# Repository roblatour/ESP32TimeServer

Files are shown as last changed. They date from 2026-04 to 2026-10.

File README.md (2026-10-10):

# ESP32 NTP Stratum 1 Time Server (version 3.0.4)

An ESP32 NTP Stratum 1 Time Server for your home network



---

## Overview

This project was born with a simple goal: create a low-budget, **Stratum 1 NTP
time server** solution with no need for periodic Linux OS updates. Rather just
set it up and let it do its job.

ESP32 Time Server

It uses a **GNSS (North America & Europe) receiver** as its time source, making
it a true Stratum 1 server — meaning it gets its time directly from satellites
rather than from another NTP server. Every device on your home network can then
synchronize to it for highly accurate local time.

---

## What's New

**Current Version (3.0+)**
- **NTPv4 Symmetric-key authentication** added for Windows 
  clients using Meinberg and Linux clients using chrony.  For more 
  information, please see [this document](misc/symmetric_key_authentication_setup.md).
- **WS2182** RGB LED support added (KY-016 support continues).

**Version 2** was a ground-up rewrite which came with a faster, more capable board 
support and a long list of accuracy, reliability, and convenience improvements over
version 1, including:

- **Higher accuracy, lower jitter** — full use of the GPS module's PPS
  (Pulse Per Second) pin disciplines the clock for sub-millisecond accuracy,
  with hardware time stamping and RFC 9769-compatible interleaved responses
  further reducing jitter for both NTPv3 and NTPv4 requests.
- **Faster, more modern hardware** — built around the WaveShare ESP32-P4-ETH
  (or the newer ESP32-P4-WIFI6-ETH), a significant step up from the
  ESP32-WROOM-32/32E used in v1.
- **Broader GNSS module support** — still works great with the recommended
  SparkFun MAX-M10S, but also supports lower-cost generic GNSS modules and now
  has experimental support for the GT-U16, which offers better reception than
  some competing receivers at the same or higher price points.
- **Wireless firmware updates** — Over-the-Ethernet OTA updates let you push
  new firmware directly from VS Code, with on-screen progress shown on the
  LCD, so you rarely need to plug in a cable after the first flash.
- **Handles more traffic** — greatly increased throughput and concurrent
  request handling, so the server keeps up even on busy networks.
- **IPv6 support** — the server now responds to NTP requests over IPv6 as
  well as IPv4.
- **Flexible networking** — set a custom MAC address or a static IP, instead
  of always relying on the device's default address and DHCP.
- **Optional LCD support** — a 4x20 LCD screen was required in v1; 
  in v2 it's entirely optional, along with an optional up time / reset button.
- **Optional RGB LED support added** — [here](misc/status_indicators.md)
  is how that is used.
- **Smart GNSS lock tracking** — improved satellite lock and PPS discipline
  tracking, with results correctly reported as Stratum 16 (undefined) if lock
  or discipline is temporarily lost, and automatic recovery once it's
  restored.
- **Quick restarts** — GPS module identity and baud rate are saved to
  non-volatile storage, so the server starts up quickly after the initial
  setup.
- **MQTT publishing** — optionally publish time server stats to an MQTT
  broker, with TF card support for queueing far more messages if the broker
  connection drops.
- **Home Assistant integration** — ready-made entity and dashboard setup
  instructions for pulling time server stats into Home Assistant.
- **Built-in self-test** — an optional startup health check lets the server
  verify its own core functionality every time it boots.
- **Testing tools and guidance** — instructions, tools, and links for
  measuring jitter, drift, RFC 9769 compliance, memory usage, and server
  performance under stress.
- **Updated 3D printed case** — enclosure files refreshed for the new
  WaveShare ESP32-P4-ETH board.

 **Version 1** described in detail [here](https://hackaday.io/project/189309-esp32-ntp-time-server-stratum-1) was built for Arduino / PlatformIO and remains available
 [here](https://github.com/roblatour/ESP32TimeServer/releases/tag/v1.0.0.0).
>
([Detailed release history](https://github.com/roblatour/ESP32TimeServer/releases))

---

## Hardware

| Qty | Item |
| --- | --- |
| 1 | WaveShare [ESP32-P4-ETH](https://www.waveshare.com/esp32-p4-eth.htm?sku=32086) or [ESP32-P4-WIFI6-ETH](https://www.waveshare.com/esp32-p4-wifi6-poe-eth.htm?sku=32832) development board (with or without optional PoE) <sup>1 2</sup> |
| 1 | GPS/GNSS module [Recommended: SparkFun GNSS Receiver Breakout - MAX-M10S (Qwiic)](https://www.sparkfun.com/sparkfun-gnss-receiver-breakout-max-m10s-qwiic.html) <sup>2</sup>. Additionally, experimental support for the [GT U16](https://www.aliexpress.com/item/1005008288311771.html) has been added in version 2.9 - this receiver offers superior reception when coupled with the right antenna (see notes below).  Additionally, while some lower-cost generic modules UBlox compliant receivers are supported, those without a PPS pin are no longer supported. |
| 1 | GPS/GNSS antenna with SMA connector ([SparkFun GPS/GNSS Magnetic Mount Antenna - 3m (SMA)](https://www.sparkfun.com/products/14986)) <sup>2</sup>. Alternatively the GT U16 with an L1/L5 antenna offers superior reception.  However, in my testing I used the [3M SMA W70C](https://www.aliexpress.com/item/1005008421771962.html?spm=a2g0o.order_list.order_list_main.11.7a7f1802GCXbvZ) L1/L2/L5 antenna an [IPEX to SMA adapter](https://www.aliexpress.com/item/1005009047225776.html) and got very good results (I have the antenna bundled with the GT U16 (link above) on order and when I get it and test it I will update this page). |
| 1 | _(Optional)_ TF Card, formatted as FAT32, if you're using MQTT and want more than four messages queued should broker communications be down) <sup>2</sup> |
| 1 | _(Optional)_ RGB LED: KY-016 ([AliExpress](https://www.aliexpress.com/item/32763280158.html)) or WS2812 ([AliExpress](https://www.aliexpress.com/item/1005009109749689.html)) with a 470&Omega; resistor and optional lens cap ([AliExpress](https://www.aliexpress.com/store/625859)) |
| 1 | _(Optional)_ 4×20 I²C LCD display with HD44780 controller with PCF8574 I²C backpack ([AliExpress](https://www.aliexpress.com/item/1005006829045609.html)) <sup>2</sup> |
| 1 | _(Optional)_ Momentary push button for displaying up time and triggering a reset ([AliExpress](https://www.aliexpress.com/item/1005004066257419.html)) <sup>2</sup> |
| 1 | _(Optional)_ USB C extension cable (with right angle end) ([AliExpress](https://www.aliexpress.com/item/1005006584965187.html)) <sup>2</sup> + two M3*8 |
| — | Miscellaneous: Ethernet cable, female dupont connection wires, small 4" .1" zip ties, solder <sup>2</sup> |
| — | A PoE-capable switch, PoE injector, **or** USB-C power supply and USB-C cable |

> ⚠️ **WARNING — Do NOT power the ESP32-P4-POE-ETH or the ESP32-P4-WIFI6-POE-ETH
> via both its USB-C connector and a PoE powered Ethernet cable at the same time.**
> Powering from both simultaneously may damage the ESP32-P4-ETH board, POE switch,
> or device providing USB power. Either power source alone is sufficient to
> power the board, GPS module, and LCD screen.

<sup>1</sup> See notes in the 'What's New in Version 2' section above.

<sup>2</sup> _(Optional)_ there are 3D Printable Case designed for use
with ESP32-P4_ETH and these specific components (for more information see below).

_(Also Optional)_ To cut down on wiring a PCB can be used. One designed
to work within this project's 3D printed enclosure is available in the
[`PCB`](./PCB) folder. If your interested, please review the `Readme.md` file in
that folder for more information.

### Wiring

#### GPS module → ESP32-P4-ETH _(mandatory)_

| GPS pin | ESP32-P4-ETH pin |
| --- | --- |
| GND | GND |
| VCC | 3V3 |
| PPS | GPIO 20 |
| TXD | GPIO 21 (RX) |
| RXD | GPIO 22 (TX) |

**Pro Tip:** (Optionally) Adding a capacitor between the GNSS module's Vcc and GND power pins,
placed as close as possible to those pins, can improve GNSS power supply stability. Use a
100nf (aka 0.1μf, aka 104) ceramic capacitor, rated at least 50v, 
such as [this one](https://www.aliexpress.com/item/1005004469852680.html).

**Important:**
 
Some GNSS receivers and breakout boards provide a 3.3v PPS (Pulse-Per-Second) output pin
while others provide a 5v PPS output pin.

1. Only connect a 3.3v PPS pin to an ESP32 GPIO pin, never connect a 5v PPS pin to an ESP32 GPIO pin

2. For the wire between the ESP32-P4's GPIO pin and the GNSS Receiver's PPS pin
use as short and as well connect wire as possible; a standard copper Dupont wire
will be fine assuming its gauge is between 24 AWG and 28 AWG

3. The GNSS GND must be connected to the ESP32 GND

Also of note, the above PPS, TX, and RX pin selections were changed in version 2.4 for better
forward and backward compatibility between revisions of the ESP32-P4 chip.
However, if an earlier version of the software has been working fine for you
then you may be able to use the old pin specifications if you want to avoid
rewiring your project. Please see the ESP32TimeServerSettings.h file for more
information.

#### Up time / Reset button → ESP32-P4-ETH _(optional)_

| Button | ESP32-P4-ETH pin |
| --- | --- |
| One terminal | GND |
| The other terminal | GPIO 3 |

#### WS2812 RGB LED _(optional)_

| LCD pin | | ESP32-P4-ETH pin |
| --- | --- | --- |
| GND | | GND |
| DI | 470&Omega; resistor | GPIO 4 |
| 5v | | V5 / VBUS |
> **Important** with the WS2812 a 470&Omega; resistor is require between the DI and GPIO 4 pin

#### KY-016 RGB LED _(optional)_

| LCD pin | ESP32-P4-ETH pin |
| --- | --- |
| GND | GND |
| BLUE | GPIO 4 |
| GREEN | GPIO 5 |
| RED | GPIO 6 |

#### LCD 2004 (HD44780 + PCF8574 I²C backpack) → ESP32-P4-ETH _(optional)_

| LCD pin | ESP32-P4-ETH pin |
| --- | --- |
| GND | GND |
| VCC | 3V3 |
| SLC/SCL | GPIO 7 |
| SDA | GPIO 8 |

Refer to the pin definitions in
[`main/ESP32TimeServerSettings.h`](./main/ESP32TimeServerSettings.h).

---

## 3D Printed Case

A downloadable 3D printable enclosure designed for use the WaveShare
ESP32-P4-ETH (with or without the POE hat) + Sparkfun GPS boards is included in
the [`3D printable case/`](./3D%20printable%20case/) folder. Both `.stl`
(print-ready) and `.f3z` (Fusion 360 editable source) files are provided so you
can tweak the design to suit your needs.

> **Note:** the 3D printable enclosure files also includes the needed models for
> version 1 (used an Olimex ESP32-PoE-ISO Rev. B dev board).

---

## Software

### Build and development environment

**To build and flash ESP32TimeServer** you will need **Espressif's ESP-IDF v6.1** or above. 
If you don't already have this software installed, just follow the install instructions
directly below:

https://docs.espressif.com/projects/esp-idf/en/stable/esp32/get-started/index.html

which include these links to get it:

[Installation of ESP-IDF and Tools on Windows](https://docs.espressif.com/projects/esp-idf/en/stable/esp32/get-started/windows-setup.html)

[Installation of ESP-IDF and Tools on Linux](https://docs.espressif.com/projects/esp-idf/en/stable/esp32/get-started/linux-setup.html)

[Installation of ESP-IDF and Tools on macOS](https://docs.espressif.com/projects/esp-idf/en/stable/esp32/get-started/macos-setup.html)

If you want to further develop the project, Visual Studio Code with the ESP-IDF extension is recommended.
However, they are not needed to build and flash the project - the instructions for that are below.

Both Visual Studio Code (Community Edition) and the ESP-IDF extension are free to download and use.
Here is where you can find more information about them and get your copies:

- **[Visual Studio Code](https://code.visualstudio.com/)**
- **[Espressif ESP-IDF Extension for VS Code](https://marketplace.visualstudio.com/items?itemName=espressif.esp-idf-extension)**

#### **For Linux users:**
A kind user of this project has shared more detailed environment setup, build and flash instructions specific to Linux (Debian 13) - these can be found [here](misc/Linux_specific_setup_instructions.md)

### Dependencies

The
[`SparkFun u-blox GNSS Arduino Library v3`](https://github.com/sparkfun/SparkFun_u-blox_GNSS_v3)
(v3.1.14) is included as a **git submodule** in
[`3rdparty/SparkFun_u-blox_GNSS_v3`](./3rdparty/SparkFun_u-blox_GNSS_v3). The
local component wrapper in `components/SparkFun_u-blox_GNSS_v3` builds it from
that checked-out submodule.

The remaining dependencies are managed automatically via the ESP-IDF Component
Manager (declared in [`main/idf_component.yml`](./main/idf_component.yml)):

- `esp-idf-lib/hd44780` — LCD driver
- `esp-idf-lib/pcf8574` — I²C LCD backpack driver
- `espressif/arduino-esp32` — Arduino compatibility layer for OTA and serial
- `espressif/mqtt` — MQTT client used for optional reporting

> **Note:** The ESP-IDF Component Manager resolves these dependencies
> dynamically at build time. A `dependencies.lock` file is generated locally on
> first build but is intentionally not committed because it is git-ignored.

## Setup

### Setup Step 1 - Download

Create a folder for this project, clone this repository into it, and update the
SparkFun library within it. For example:

```cmd
c:
```

```cmd
mkdir c:\temp\ESP32TimeServerProject
```

```cmd
cd \temp\ESP32TimeserverProject
```

```cmd
git clone --recursive https://github.com/roblatour/ESP32TimeServer
```

```cmd
cd ESP32TimeServer
```

```cmd
git submodule update --init --recursive
```

### Setup Step 2 - Configuration

All user-configurable settings — GPIO pins, GPS options, LCD options, button
support, time zone, etc. — are centralized in:

```plaintext
main/ESP32TimeServerSettings.h
```

Edit this file to match your desired hardware setup before building.

> **Note:** The settings file indicates whether certain features are enabled.
> These include support for an Uptime/Restart Button, a Liquid Crystal Display,
> MQTT reporting, and Over the Ethernet Updates. Please also note, that if a
> Liquid Crystal Display is **not** connected, `LIQUID_CRYSTAL_DISPLAY_ENABLED`
> **must** be `0` (disabled) or a critical runtime error will occur.

### Setup Step 3 - Build

Open a Command Prompt, load the ESP-IDF 6.1 environment, and remove any
existing generated configuration before building. The first build downloads the
Component Manager dependencies into `managed_components`; this generated folder
is not part of the repository. 

Enter the commands below to setup the build environment and build the project:

```cmd
call C:\esp\v6.1\esp-idf\export.bat
```
```cmd
if exist sdkconfig del sdkconfig
```

You will need to know your ESP32-P4 chip's revision number to build the program. To determine it connect your ESP32-P4 development board to your computer via a USB cable and enter the following command:

```cmd
esptool.py -p COMx flash-id
```

> Note: Replace `COMx` with your actual serial port. For example: COM6

The output of the above includes chip type and revision number.

Next, use the command below matching your ESP32-P4's chip revision number to build the project:

- For ESP32-P4 chips at revision 3.1 and above (including the 
  **WaveShare ESP32-P4-WIFI6-POE-ETH and newer WaveShare 
  ESP32-P4-ETH** development boards):

  ```cmd
  idf.py -D SDKCONFIG_DEFAULTS="sdkconfig.defaults;config/esp32p4_rev_v3_1.defaults" set-target esp32p4 build
  ```
- For ESP32-P4 chips at revision 3.0:

  ```cmd
  idf.py -D SDKCONFIG_DEFAULTS="sdkconfig.defaults;config/esp32p4_rev_v3_0.defaults" set-target esp32p4 build
  ```
- For older ESP32-P4 chips with revisions prior to version 3.0 (including older 
  **Waveshare ESP32-P4-ETH** development boards):

  ```cmd
  idf.py -D SDKCONFIG_DEFAULTS="sdkconfig.defaults;config/esp32p4_rev_pre_v3.defaults" set-target esp32p4 build
  ```

### Setup Step 4 - Flash

In the same Command Prompt where ESP-IDF 6.1 was loaded:

```cmd
idf.py -p COMx flash monitor
```

> Note: Replace `COMx` with your actual serial port. For example: COM6
>
> **Important:** Do not use `--force` to flash an image to an earlier revision
> ESP32-P4.

### Over The Ethernet (OTE) Updates

Following the initial flash, OTE updates can be performed if
`OTE_UPDATES_ENABLED` was set to `1` (Enabled) for the initial build and flash.

A VS Code task **"ESP-IDF: OTE Upload over Ethernet"** is included in
`.vscode/tasks.json`. It builds the firmware and deploys it to the device over
Ethernet using `espota.py`, so no USB cable is needed after the first flash.
Alternatively, use the terminal command in
[`UsefulPowerShellCommands.md`](./misc/UsefullPowerShellCommands.md) in the
`misc` folder.

---

## Setting up your Network / Systems to make use of the ESP32 Time Server

Please see [`Setup.md`](misc/Setup.md)

---

## Validating Your Time Server

Once running, and with your Network and System changes setup, you can validate
accuracy at [https://time.is](https://time.is).

You're also welcome to use this open source software (also developed by me) to
stress test your time server:

<https://github.com/roblatour/TimeServerStressTest>

---

## License

This project is released under the **MIT License** — see the [LICENSE](LICENSE)
file for details.

---

## Supporting This Project

To help support this project, or to just say thanks, you're welcome to 'buy me a
coffee'.

[buy me a coffee](https://www.buymeacoffee.com/roblatour)

---

Copyright © 2026 Rob Latour

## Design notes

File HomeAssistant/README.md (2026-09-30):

# ESP32 Time Server — Home Assistant Dashboard Card Setup

This guide covers how to integrate the ESP32 Time Server with Home Assistant and
display a status dashboard card. It is **not** an exhaustive write-up; it is
intended to get things up and running within an already existing Home Assistant
implementation.

The steps covered are:

1. Install and configure the Mosquitto MQTT broker add-on
2. Configure `mqtt.yaml` with the ESP32 Time Server sensors
3. Update `configuration.yaml` with an MQTT reference and template sensors
4. Reload the Home Assistant YAML configuration
5. Add a dashboard entity card

When complete, your dashboard will include a card like this:

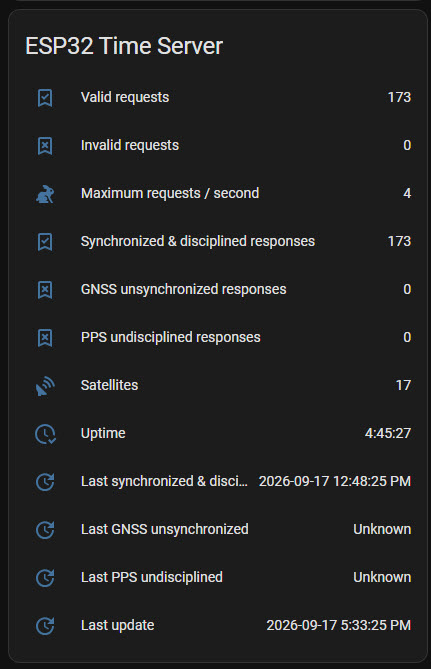
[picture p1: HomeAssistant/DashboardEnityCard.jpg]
ESP32 Time Server Dashboard Card


---

## Step 1: Install the Mosquitto MQTT Broker

The ESP32 Time Server publishes its status data over MQTT. Home Assistant needs
a running MQTT broker to receive those messages.

The recommended broker for Home Assistant is the Mosquitto broker add-on. Follow
the official Home Assistant documentation to install and configure it before
continuing:

- **MQTT integration overview:**
  <https://www.home-assistant.io/integrations/mqtt/>
- **Mosquitto broker add-on:**
  <https://github.com/home-assistant/addons/blob/master/mosquitto/DOCS.md>

Once the Mosquitto broker is running and the MQTT integration is connected to
it, proceed to Step 2.

---

## Step 2: Configure mqtt.yaml

The MQTT sensors tell Home Assistant how to extract individual values from the
JSON payload that the ESP32 Time Server publishes to the
`ESP32TimeServer/report` topic.

Choose **one** of the three options below based on your current setup. After
completing this step, proceed to the matching option in Step 3.

### A — Create a new mqtt.yaml file

Use this option if you do **not** already have an `mqtt.yaml` file.

1. Create a new file called `mqtt.yaml` in your Home Assistant configuration
   directory (the same folder that contains `configuration.yaml`).
2. Add the following content:

```yaml

  sensor:
    # ============================
    # CURRENT
    # ============================
    - name: "NTP Time"
      state_topic: "ESP32TimeServer/report"
      value_template: "{{ value_json.current.time }}"

    - name: "NTP Uptime"
      state_topic: "ESP32TimeServer/report"
      value_template: "{{ value_json.current.uptime }}"
      unit_of_measurement: "s"

    - name: "Ethernet Up"
      state_topic: "ESP32TimeServer/report"
      value_template: "{{ value_json.current.ethernet_up }}"

    - name: "GNSS Synchronized"
      state_topic: "ESP32TimeServer/report"
      value_template: "{{ value_json.current.gnss_synchronized }}"

    - name: "GNSS Locked"
      state_topic: "ESP32TimeServer/report"
      value_template: "{{ value_json.current.gnss_synchronized_indicators.locked }}"

    - name: "GNSS Timing Valid"
      state_topic: "ESP32TimeServer/report"
      value_template: "{{ value_json.current.gnss_synchronized_indicators.timing }}"

    - name: "GNSS GPS Valid"
      state_topic: "ESP32TimeServer/report"
      value_template: "{{ value_json.current.gnss_synchronized_indicators.gps_valid }}"

    - name: "GNSS Sync Fresh"
      state_topic: "ESP32TimeServer/report"
      value_template: "{{ value_json.current.gnss_synchronized_indicators.sync_fresh }}"

    - name: "GNSS Sanity Check Passed"
      state_topic: "ESP32TimeServer/report"
      value_template: "{{ value_json.current.gnss_synchronized_indicators.sanity_check_passed }}"

    - name: "PPS Disciplined"
      state_topic: "ESP32TimeServer/report"
      value_template: "{{ value_json.current.pps_disciplined }}"

    - name: "PPS Signals Present"
      state_topic: "ESP32TimeServer/report"
      value_template: "{{ value_json.current.pps_disciplined_indicators.pps_signals_present }}"

    - name: "PPS Discipline Active"
      state_topic: "ESP32TimeServer/report"
      value_template: "{{ value_json.current.pps_disciplined_indicators.discipline_active }}"

    - name: "PPS Synchronized"
      state_topic: "ESP32TimeServer/report"
      value_template: "{{ value_json.current.pps_disciplined_indicators.pps_synchronized }}"

    - name: "Satellites Current"
      state_topic: "ESP32TimeServer/report"
      value_template: "{{ value_json.current.satellites }}"

    # ============================
    # MEMORY
    # ============================
    - name: "Malloc DMA"
      state_topic: "ESP32TimeServer/report"
      value_template: "{{ value_json.current.memory.malloc_cap_dma }}"

    - name: "Free Heap"
      state_topic: "ESP32TimeServer/report"
      value_template: "{{ value_json.current.memory.free_heap }}"

    - name: "Minimum Free Heap"
      state_topic: "ESP32TimeServer/report"
      value_template: "{{ value_json.current.memory.minimum_free_heap }}"

    - name: "Largest Free 8-bit Block"
      state_topic: "ESP32TimeServer/report"
      value_template: "{{ value_json.current.memory.largest_free_8bit_block }}"

    # ============================
    # QUEUED MESSAGES
    # ============================
    - name: "Queued Held"
      state_topic: "ESP32TimeServer/report"
      value_template: "{{ value_json.queued_messages.held }}"

    - name: "Queued Discarded"
      state_topic: "ESP32TimeServer/report"
      value_template: "{{ value_json.queued_messages.discarded }}"

    # ============================
    # THIS PERIOD
    # ============================
    - name: "Ethernet Up Seconds"
      state_topic: "ESP32TimeServer/report"
      value_template: "{{ value_json.this_period.ethernet_up_secs }}"
      unit_of_measurement: "s"

    - name: "PPS Pulses"
      state_topic: "ESP32TimeServer/report"
      value_template: "{{ value_json.this_period.pps_pulses }}"

    - name: "GNSS Locked Seconds"
      state_topic: "ESP32TimeServer/report"
      value_template: "{{ value_json.this_period.gnss_locked_secs }}"
      unit_of_measurement: "s"

    - name: "Satellites Min"
      state_topic: "ESP32TimeServer/report"
      value_template: "{{ value_json.this_period.satellites.min }}"

    - name: "Satellites Max"
      state_topic: "ESP32TimeServer/report"
      value_template: "{{ value_json.this_period.satellites.max }}"

    - name: "NTP Requests Valid"
      state_topic: "ESP32TimeServer/report"
      value_template: "{{ value_json.this_period.ntp.requests.valid }}"

    - name: "NTP Requests Invalid"
      state_topic: "ESP32TimeServer/report"
      value_template: "{{ value_json.this_period.ntp.requests.invalid }}"
      
    - name: "NTP Requests Authenticated Valid"
      state_topic: "ESP32TimeServer/report"
      value_template: "{{ value_json.this_period.ntp.requests.authenticated.valid }}"

    - name: "NTP Requests Authenticated Invalid"
      state_topic: "ESP32TimeServer/report"
      value_template: "{{ value_json.this_period.ntp.requests.authenticated.invalid }}"

    - name: "NTP Requests Unauthenticated Valid"
      state_topic: "ESP32TimeServer/report"
      value_template: "{{ value_json.this_period.ntp.requests.unauthenticated.valid }}"

    - name: "NTP Requests Unauthenticated Invalid"
      state_topic: "ESP32TimeServer/report"
      value_template: "{{ value_json.this_period.ntp.requests.unauthenticated.invalid }}"

    - name: "Load Shedding"
      state_topic: "ESP32TimeServer/report"
      value_template: "{{ value_json.this_period.ntp.requests.load_shedding }}"

    - name: "NTP Telemetry Dropped"
      state_topic: "ESP32TimeServer/report"
      value_template: "{{ value_json.this_period.ntp.requests.telemetry_dropped }}"

    - name: "NTP Max Requests Per Second"
      state_topic: "ESP32TimeServer/report"
      value_template: "{{ value_json.this_period.ntp.requests.max_per_second }}"

    - name: "NTP Responses Synchronized & Disciplined"
      state_topic: "ESP32TimeServer/report"
      value_template: "{{ value_json.this_period.ntp.responses.synchronized_and_disciplined }}"

    - name: "NTP Responses GNSS Unsynchronized"
      state_topic: "ESP32TimeServer/report"
      value_template: "{{ value_json.this_period.ntp.responses.gnss_unsynchronized }}"

    - name: "NTP Responses PPS Undisciplined"
      state_topic: "ESP32TimeServer/report"
      value_template: "{{ value_json.this_period.ntp.responses.pps_undisciplined }}"

    # ============================
    # CLIENTS
    # ============================
    - name: "Clients Overflown"
      state_topic: "ESP32TimeServer/report"
      value_template: "{{ value_json.this_period.clients_overflown }}"

    # Example for client 0 (you can add more if desired)
    - name: "Client 0 Address"
      state_topic: "ESP32TimeServer/report"
      value_template: "{{ value_json.this_period.clients[0].address }}"

    - name: "Client 0 Requests"
      state_topic: "ESP32TimeServer/report"
      value_template: "{{ value_json.this_period.clients[0].requests }}"

    # ============================
    # HISTORICAL
    # ============================
    - name: "Last Synchronized & Disciplined"
      state_topic: "ESP32TimeServer/report"
      value_template: "{{ value_json.historical.gnss_receiver_last.synchronized_and_disciplined }}"

    - name: "Last GNSS Unsynchronized"
      state_topic: "ESP32TimeServer/report"
      value_template: "{{ value_json.historical.gnss_receiver_last.gnss_unsynchronized }}"

    - name: "Last PPS Undisciplined"
      state_topic: "ESP32TimeServer/report"
      value_template: "{{ value_json.historical.gnss_receiver_last.pps_undisciplined }}"

```

### B — Append to an existing mqtt.yaml

Use this option if you already have an `mqtt.yaml` file that contains a
`sensor:` list.

1. Open your existing `mqtt.yaml`.
2. Scroll to the end of the `sensor:` list and append the entries below. Each
   entry is indented two spaces (to sit under the existing `sensor:` key). If
   your file does not yet have a `sensor:` key, add `sensor:` on its own line
   first, then paste the entries beneath it.

```yaml
  
  # only add the sensor key line below if your existing file currently doesn't already have a sensor key line
  sensor:

    # ============================
    # CURRENT
    # ============================
    - name: "NTP Time"
      state_topic: "ESP32TimeServer/report"
      value_template: "{{ value_json.current.time }}"

    - name: "NTP Uptime"
      state_topic: "ESP32TimeServer/report"
      value_template: "{{ value_json.current.uptime }}"
      unit_of_measurement: "s"

    - name: "Ethernet Up"
      state_topic: "ESP32TimeServer/report"
      value_template: "{{ value_json.current.ethernet_up }}"

    - name: "GNSS Synchronized"
      state_topic: "ESP32TimeServer/report"
      value_template: "{{ value_json.current.gnss_synchronized }}"

    - name: "GNSS Locked"
      state_topic: "ESP32TimeServer/report"
      value_template: "{{ value_json.current.gnss_synchronized_indicators.locked }}"

    - name: "GNSS Timing Valid"
      state_topic: "ESP32TimeServer/report"
      value_template: "{{ value_json.current.gnss_synchronized_indicators.timing }}"

    - name: "GNSS GPS Valid"
      state_topic: "ESP32TimeServer/report"
      value_template: "{{ value_json.current.gnss_synchronized_indicators.gps_valid }}"

    - name: "GNSS Sync Fresh"
      state_topic: "ESP32TimeServer/report"
      value_template: "{{ value_json.current.gnss_synchronized_indicators.sync_fresh }}"

    - name: "GNSS Sanity Check Passed"
      state_topic: "ESP32TimeServer/report"
      value_template: "{{ value_json.current.gnss_synchronized_indicators.sanity_check_passed }}"

    - name: "PPS Disciplined"
      state_topic: "ESP32TimeServer/report"
      value_template: "{{ value_json.current.pps_disciplined }}"

    - name: "PPS Signals Present"
      state_topic: "ESP32TimeServer/report"
      value_template: "{{ value_json.current.pps_disciplined_indicators.pps_signals_present }}"

    - name: "PPS Discipline Active"
      state_topic: "ESP32TimeServer/report"
      value_template: "{{ value_json.current.pps_disciplined_indicators.discipline_active }}"

    - name: "PPS Synchronized"
      state_topic: "ESP32TimeServer/report"
      value_template: "{{ value_json.current.pps_disciplined_indicators.pps_synchronized }}"

    - name: "Satellites Current"
      state_topic: "ESP32TimeServer/report"
      value_template: "{{ value_json.current.satellites }}"

    # ============================
    # MEMORY
    # ============================
    - name: "Malloc DMA"
      state_topic: "ESP32TimeServer/report"
      value_template: "{{ value_json.current.memory.malloc_cap_dma }}"

    - name: "Free Heap"
      state_topic: "ESP32TimeServer/report"
      value_template: "{{ value_json.current.memory.free_heap }}"

    - name: "Minimum Free Heap"
      state_topic: "ESP32TimeServer/report"
      value_template: "{{ value_json.current.memory.minimum_free_heap }}"

    - name: "Largest Free 8-bit Block"
      state_topic: "ESP32TimeServer/report"
      value_template: "{{ value_json.current.memory.largest_free_8bit_block }}"

    # ============================
    # QUEUED MESSAGES
    # ============================
    - name: "Queued Held"
      state_topic: "ESP32TimeServer/report"
      value_template: "{{ value_json.queued_messages.held }}"

    - name: "Queued Discarded"
      state_topic: "ESP32TimeServer/report"
      value_template: "{{ value_json.queued_messages.discarded }}"

    # ============================
    # THIS PERIOD
    # ============================
    - name: "Ethernet Up Seconds"
      state_topic: "ESP32TimeServer/report"
      value_template: "{{ value_json.this_period.ethernet_up_secs }}"
      unit_of_measurement: "s"

    - name: "PPS Pulses"
      state_topic: "ESP32TimeServer/report"
      value_template: "{{ value_json.this_period.pps_pulses }}"

    - name: "GNSS Locked Seconds"
      state_topic: "ESP32TimeServer/report"
      value_template: "{{ value_json.this_period.gnss_locked_secs }}"
      unit_of_measurement: "s"

    - name: "Satellites Min"
      state_topic: "ESP32TimeServer/report"
      value_template: "{{ value_json.this_period.satellites.min }}"

    - name: "Satellites Max"
      state_topic: "ESP32TimeServer/report"
      value_template: "{{ value_json.this_period.satellites.max }}"

    - name: "NTP Requests Valid"
      state_topic: "ESP32TimeServer/report"
      value_template: "{{ value_json.this_period.ntp.requests.valid }}"

    - name: "NTP Requests Invalid"
      state_topic: "ESP32TimeServer/report"
      value_template: "{{ value_json.this_period.ntp.requests.invalid }}"

    - name: "NTP Requests Authenticated Valid"
      state_topic: "ESP32TimeServer/report"
      value_template: "{{ value_json.this_period.ntp.requests.authenticated.valid }}"

    - name: "NTP Requests Authenticated Invalid"
      state_topic: "ESP32TimeServer/report"
      value_template: "{{ value_json.this_period.ntp.requests.authenticated.invalid }}"

    - name: "NTP Requests Unauthenticated Valid"
      state_topic: "ESP32TimeServer/report"
      value_template: "{{ value_json.this_period.ntp.requests.unauthenticated.valid }}"

    - name: "NTP Requests Unauthenticated Invalid"
      state_topic: "ESP32TimeServer/report"
      value_template: "{{ value_json.this_period.ntp.requests.unauthenticated.invalid }}"

    - name: "Load Shedding"
      state_topic: "ESP32TimeServer/report"
      value_template: "{{ value_json.this_period.ntp.requests.load_shedding }}"

    - name: "NTP Telemetry Dropped"
      state_topic: "ESP32TimeServer/report"
      value_template: "{{ value_json.this_period.ntp.requests.telemetry_dropped }}"

    - name: "NTP Max Requests Per Second"
      state_topic: "ESP32TimeServer/report"
      value_template: "{{ value_json.this_period.ntp.requests.max_per_second }}"

    - name: "NTP Responses Synchronized & Disciplined"
      state_topic: "ESP32TimeServer/report"
      value_template: "{{ value_json.this_period.ntp.responses.synchronized_and_disciplined }}"

    - name: "NTP Responses GNSS Unsynchronized"
      state_topic: "ESP32TimeServer/report"
      value_template: "{{ value_json.this_period.ntp.responses.gnss_unsynchronized }}"

    - name: "NTP Responses PPS Undisciplined"
      state_topic: "ESP32TimeServer/report"
      value_template: "{{ value_json.this_period.ntp.responses.pps_undisciplined }}"

    # ============================
    # CLIENTS
    # ============================
    - name: "Clients Overflown"
      state_topic: "ESP32TimeServer/report"
      value_template: "{{ value_json.clients_overflown }}"

    # Example for client 0 (you can add more if desired)
    - name: "Client 0 Address"
      state_topic: "ESP32TimeServer/report"
      value_template: "{{ value_json.clients[0].address }}"

    - name: "Client 0 Requests"
      state_topic: "ESP32TimeServer/report"
      value_template: "{{ value_json.clients[0].requests }}"

    # ============================
    # HISTORICAL
    # ============================
    - name: "GNSS Last Synchronized & Disciplined"
      state_topic: "ESP32TimeServer/report"
      value_template: "{{ value_json.historical.gnss_receiver_last.synchronized_and_disciplined }}"

    - name: "GNSS Last Unsynchronized"
      state_topic: "ESP32TimeServer/report"
      value_template: "{{ value_json.historical.gnss_receiver_last.gnss_unsynchronized }}"

    - name: "PPS Last Undisciplined"
      state_topic: "ESP32TimeServer/report"
      value_template: "{{ value_json.historical.gnss_receiver_last.pps_undisciplined }}"

```

### C — Keep a separate mqtt_esp32timeserver.yaml file

Use this option if you want to keep the ESP32 Time Server sensors in a dedicated
file alongside your existing `mqtt.yaml`.

Home Assistant's `!include_dir_merge_list` directive merges all YAML files in a
directory into a single list. The files in that directory must be plain YAML
lists (no top-level `sensor:` key).

1. Create a subdirectory called `mqtt_sensors/` inside your Home Assistant
   configuration directory.
2. Open your existing `mqtt.yaml` and copy its sensor entries (the lines under
   the `sensor:` key) into a new file called `mqtt_sensors/mqtt.yaml`. The new
   file should begin directly with `- name:` entries — do **not** include the
   `sensor:` header line.
3. Create `mqtt_sensors/mqtt_esp32timeserver.yaml` with the content below (also
   a plain list — no `sensor:` header):

```yaml
 
    # ============================
    # CURRENT
    # ============================
    - name: "NTP Time"
      state_topic: "ESP32TimeServer/report"
      value_template: "{{ value_json.current.time }}"

    - name: "NTP Uptime"
      state_topic: "ESP32TimeServer/report"
      value_template: "{{ value_json.current.uptime }}"
      unit_of_measurement: "s"

    - name: "Ethernet Up"
      state_topic: "ESP32TimeServer/report"
      value_template: "{{ value_json.current.ethernet_up }}"

    - name: "GNSS Synchronized"
      state_topic: "ESP32TimeServer/report"
      value_template: "{{ value_json.current.gnss_synchronized }}"

    - name: "GNSS Locked"
      state_topic: "ESP32TimeServer/report"
      value_template: "{{ value_json.current.gnss_synchronized_indicators.locked }}"

    - name: "GNSS Timing Valid"
      state_topic: "ESP32TimeServer/report"
      value_template: "{{ value_json.current.gnss_synchronized_indicators.timing }}"

    - name: "GNSS GPS Valid"
      state_topic: "ESP32TimeServer/report"
      value_template: "{{ value_json.current.gnss_synchronized_indicators.gps_valid }}"

    - name: "GNSS Sync Fresh"
      state_topic: "ESP32TimeServer/report"
      value_template: "{{ value_json.current.gnss_synchronized_indicators.sync_fresh }}"

    - name: "GNSS Sanity Check Passed"
      state_topic: "ESP32TimeServer/report"
      value_template: "{{ value_json.current.gnss_synchronized_indicators.sanity_check_passed }}"

    - name: "PPS Disciplined"
      state_topic: "ESP32TimeServer/report"
      value_template: "{{ value_json.current.pps_disciplined }}"

    - name: "PPS Signals Present"
      state_topic: "ESP32TimeServer/report"
      value_template: "{{ value_json.current.pps_disciplined_indicators.pps_signals_present }}"

    - name: "PPS Discipline Active"
      state_topic: "ESP32TimeServer/report"
      value_template: "{{ value_json.current.pps_disciplined_indicators.discipline_active }}"

    - name: "PPS Synchronized"
      state_topic: "ESP32TimeServer/report"
      value_template: "{{ value_json.current.pps_disciplined_indicators.pps_synchronized }}"

    - name: "Satellites Current"
      state_topic: "ESP32TimeServer/report"
      value_template: "{{ value_json.current.satellites }}"

    # ============================
    # MEMORY
    # ============================
    - name: "Malloc DMA"
      state_topic: "ESP32TimeServer/report"
      value_template: "{{ value_json.current.memory.malloc_cap_dma }}"

    - name: "Free Heap"
      state_topic: "ESP32TimeServer/report"
      value_template: "{{ value_json.current.memory.free_heap }}"

    - name: "Minimum Free Heap"
      state_topic: "ESP32TimeServer/report"
      value_template: "{{ value_json.current.memory.minimum_free_heap }}"

    - name: "Largest Free 8-bit Block"
      state_topic: "ESP32TimeServer/report"
      value_template: "{{ value_json.current.memory.largest_free_8bit_block }}"

    # ============================
    # QUEUED MESSAGES
    # ============================
    - name: "Queued Held"
      state_topic: "ESP32TimeServer/report"
      value_template: "{{ value_json.queued_messages.held }}"

    - name: "Queued Discarded"
      state_topic: "ESP32TimeServer/report"
      value_template: "{{ value_json.queued_messages.discarded }}"

    # ============================
    # THIS PERIOD
    # ============================
    - name: "Ethernet Up Seconds"
      state_topic: "ESP32TimeServer/report"
      value_template: "{{ value_json.this_period.ethernet_up_secs }}"
      unit_of_measurement: "s"

    - name: "PPS Pulses"
      state_topic: "ESP32TimeServer/report"
      value_template: "{{ value_json.this_period.pps_pulses }}"

    - name: "GNSS Locked Seconds"
      state_topic: "ESP32TimeServer/report"
      value_template: "{{ value_json.this_period.gnss_locked_secs }}"
      unit_of_measurement: "s"

    - name: "Satellites Min"
      state_topic: "ESP32TimeServer/report"
      value_template: "{{ value_json.this_period.satellites.min }}"

    - name: "Satellites Max"
      state_topic: "ESP32TimeServer/report"
      value_template: "{{ value_json.this_period.satellites.max }}"

    - name: "NTP Requests Valid"
      state_topic: "ESP32TimeServer/report"
      value_template: "{{ value_json.this_period.ntp.requests.valid }}"

    - name: "NTP Requests Invalid"
      state_topic: "ESP32TimeServer/report"
      value_template: "{{ value_json.this_period.ntp.requests.invalid }}"

    - name: "NTP Requests Authenticated Valid"
      state_topic: "ESP32TimeServer/report"
      value_template: "{{ value_json.this_period.ntp.requests.authenticated.valid }}"

    - name: "NTP Requests Authenticated Invalid"
      state_topic: "ESP32TimeServer/report"
      value_template: "{{ value_json.this_period.ntp.requests.authenticated.invalid }}"

    - name: "NTP Requests Unauthenticated Valid"
      state_topic: "ESP32TimeServer/report"
      value_template: "{{ value_json.this_period.ntp.requests.unauthenticated.valid }}"

    - name: "NTP Requests Unauthenticated Invalid"
      state_topic: "ESP32TimeServer/report"
      value_template: "{{ value_json.this_period.ntp.requests.unauthenticated.invalid }}"

    - name: "Load Shedding"
      state_topic: "ESP32TimeServer/report"
      value_template: "{{ value_json.this_period.ntp.requests.load_shedding }}"

    - name: "NTP Telemetry Dropped"
      state_topic: "ESP32TimeServer/report"
      value_template: "{{ value_json.this_period.ntp.requests.telemetry_dropped }}"

    - name: "NTP Max Requests Per Second"
      state_topic: "ESP32TimeServer/report"
      value_template: "{{ value_json.this_period.ntp.requests.max_per_second }}"

    - name: "NTP Responses Synchronized & Disciplined"
      state_topic: "ESP32TimeServer/report"
      value_template: "{{ value_json.this_period.ntp.responses.synchronized_and_disciplined }}"

    - name: "NTP Responses GNSS Unsynchronized"
      state_topic: "ESP32TimeServer/report"
      value_template: "{{ value_json.this_period.ntp.responses.gnss_unsynchronized }}"

    - name: "NTP Responses PPS Undisciplined"
      state_topic: "ESP32TimeServer/report"
      value_template: "{{ value_json.this_period.ntp.responses.pps_undisciplined }}"

    # ============================
    # CLIENTS
    # ============================
    - name: "Clients Overflown"
      state_topic: "ESP32TimeServer/report"
      value_template: "{{ value_json.this_period.clients_overflown }}"

    # Example for client 0 (you can add more if desired)
    - name: "Client 0 Address"
      state_topic: "ESP32TimeServer/report"
      value_template: "{{ value_json.this_period.clients[0].address }}"

    - name: "Client 0 Requests"
      state_topic: "ESP32TimeServer/report"
      value_template: "{{ value_json.this_period.clients[0].requests }}"

    # ============================
    # HISTORICAL
    # ============================
    - name: "Last Synchronized & Disciplined"
      state_topic: "ESP32TimeServer/report"
      value_template: "{{ value_json.historical.gnss_receiver_last.synchronized_and_disciplined }}"

    - name: "Last GNSS Unsynchronized"
      state_topic: "ESP32TimeServer/report"
      value_template: "{{ value_json.historical.gnss_receiver_last.gnss_unsynchronized }}"

    - name: "Last PPS Undisciplined"
      state_topic: "ESP32TimeServer/report"
      value_template: "{{ value_json.historical.gnss_receiver_last.pps_undisciplined }}"

```

---

## Step 3: Update configuration.yaml

`configuration.yaml` needs two additions:

- A reference to the MQTT sensor file(s) created in Step 2
- Template sensors that reformat the raw MQTT values for display

Choose the option that matches what you did in Step 2. Once done, proceed to
Step 4 to reload the configuration.

### Option A — configuration.yaml with a new mqtt.yaml

Add the following line (it should not already be there):

```yaml
mqtt: !include mqtt.yaml
```

Then add the template sensors below. If `configuration.yaml` already has a
`template:` key, only add the `- sensor:` blocks under it. Otherwise add the
complete block shown:

```yaml
  # only add the template key line below if your existing file currently doesn't already have a template key line
template:

# ******************************************************************************************
# ESP32TimeServer                                                                          *   
# ******************************************************************************************
  - sensor:
      - name: "NTP Time (Formatted)"
        state: >
          {% set raw = states('sensor.ntp_time') | string %}
          {% if raw in ['', 'None', 'unknown', 'unavailable', 'Unknown', 'Unavailable'] %}
            None
          {% else %}
            {% set formatted = as_timestamp(strptime(raw, '%Y-%m-%dT%H:%M:%S%z'))
              | timestamp_custom('%Y-%m-%d %I:%M:%S %p') %}

            {# Extract hour (positions 11–13) #}
            {% set hour = formatted[11:13] %}

            {# Remove leading zero if present #}
            {% if hour.startswith('0') %}
              {% set hour = ' ' ~ hour[1] %}
            {% endif %}

            {# Reassemble final string #}
            {{ formatted[:11] ~ hour ~ formatted[13:] }}
          {% endif %}

  - sensor:
      - name: "NTP uptime (Formatted)"
        state: >
          {% set uptime = states('sensor.ntp_uptime') | int(0) %}
          {% set days = uptime // 86400 %}
          {% set hours = (uptime % 86400) // 3600 %}
          {% set minutes = (uptime % 3600) // 60 %}
          {% set seconds = uptime % 60 %}
          {% if days > 0 %}
          {{ days }}d {{ hours }}:{{ "%02d"|format(minutes) }}:{{ "%02d"|format(seconds) }}
          {% elif hours > 0 %}
          {{ hours }}:{{ "%02d"|format(minutes) }}:{{ "%02d"|format(seconds) }}
          {% elif minutes > 0 %}
          {{ minutes }}:{{ "%02d"|format(seconds) }}
          {% else %}
          {{ seconds }}
          {% endif %}

  - sensor:
      - name: "GNSS Last Sync and Disciplined (Formatted)"
        availability: >
          {{ true }}
        state: >
          {% set raw = states('sensor.last_synchronized_disciplined') | string %}
          {% if raw in ['', 'None', 'none', 'unknown', 'unavailable', 'Unknown', 'Unavailable'] %}
            {{ 'None' }}
          {% else %}
            {% set formatted = as_timestamp(strptime(raw, '%Y-%m-%dT%H:%M:%S%z'))
              | timestamp_custom('%Y-%m-%d %I:%M:%S %p') %}

            {% set hour = formatted[11:13] %}
            {% if hour.startswith('0') %}
              {% set hour = ' ' ~ hour[1:] %}
            {% endif %}

            {{ formatted[:11] ~ hour ~ formatted[13:] }}
          {% endif %}
 
  - sensor:
      - name: "Last GNSS Unsynchronized (Formatted)"
        availability: >
          {{ true }}
        state: >
          {% set raw = states('sensor.last_gnss_unsynchronized') | string %}
          {% if raw in ['', 'None', 'none', 'unknown', 'unavailable', 'Unknown', 'Unavailable'] %}
            {{ 'None' }}
          {% else %}
            {% set formatted = as_timestamp(strptime(raw, '%Y-%m-%dT%H:%M:%S%z'))
              | timestamp_custom('%Y-%m-%d %I:%M:%S %p') %}

            {% set hour = formatted[11:13] %}
            {% if hour.startswith('0') %}
              {% set hour = ' ' ~ hour[1:] %}
            {% endif %}

            {{ formatted[:11] ~ hour ~ formatted[13:] }}
          {% endif %}

  - sensor:
      - name: "Last PPS Undisciplined (Formatted)"
        state: >
          {% set raw = states('sensor.last_pps_undisciplined') | string %}
          {% if raw in ['', 'None', 'unknown', 'unavailable', 'Unknown', 'Unavailable'] %}
            None
          {% else %}
            {% set formatted = as_timestamp(strptime(raw, '%Y-%m-%dT%H:%M:%S%z'))
              | timestamp_custom('%Y-%m-%d %I:%M:%S %p') %}

            {# Extract hour (positions 11–13) #}
            {% set hour = formatted[11:13] %}

            {# Remove leading zero if present #}
            {% if hour.startswith('0') %}
              {% set hour = ' ' ~ hour[1] %}
            {% endif %}

            {# Reassemble final string #}
            {{ formatted[:11] ~ hour ~ formatted[13:] }}
          {% endif %}
```

### Option B — configuration.yaml with an existing mqtt.yaml

Confirm that `configuration.yaml` already contains the line below. If it does
not, add it:

```yaml
mqtt: !include mqtt.yaml
```

Then add the template sensors into `configuration.yaml` exactly as described in
[Option A above](#option-a--configurationyaml-with-a-new-mqttyaml).

### Option C — configuration.yaml with a separate MQTT file

Replace the existing `mqtt: !include mqtt.yaml` line with the following so Home
Assistant merges both `mqtt_sensors/mqtt.yaml` (your existing sensors) and
`mqtt_sensors/mqtt_esp32timeserver.yaml` (the new ESP32 Time Server sensors)
from the directory created in Step 2:

```yaml
mqtt:
  sensor: !include_dir_merge_list mqtt_sensors/
```

> **Note:** Your original `mqtt.yaml` in the configuration root is no longer
> referenced after this change. The copy placed in `mqtt_sensors/mqtt.yaml` in
> Step 2 takes its place.

Then add the template sensors into `configuration.yaml` exactly as described in
[Option A above](#option-a--configurationyaml-with-a-new-mqttyaml).

---

## Step 4: Reload the Home Assistant YAML Configuration

After saving changes to `configuration.yaml` and your MQTT sensor files, reload
the configuration so Home Assistant picks up the new sensors without requiring a
full restart.

1. In Home Assistant, click **Settings** in the left sidebar.
2. Click **Tools**.
3. The **YAML** tab should already be selected, if not select it.
4. Under **YAML configuration reloading**, click **All YAML Configuration**.

Home Assistant will reload all YAML files. The ESP32 Time Server sensors will
become available once the reload completes.

---

## Step 5: Add the Dashboard Card

1. Open your Home Assistant dashboard and enter edit mode.
2. Click **Add Card**, then choose **Manual** (or click the code editor icon in
   the card picker).
3. Replace any placeholder text in the editor with the YAML below.

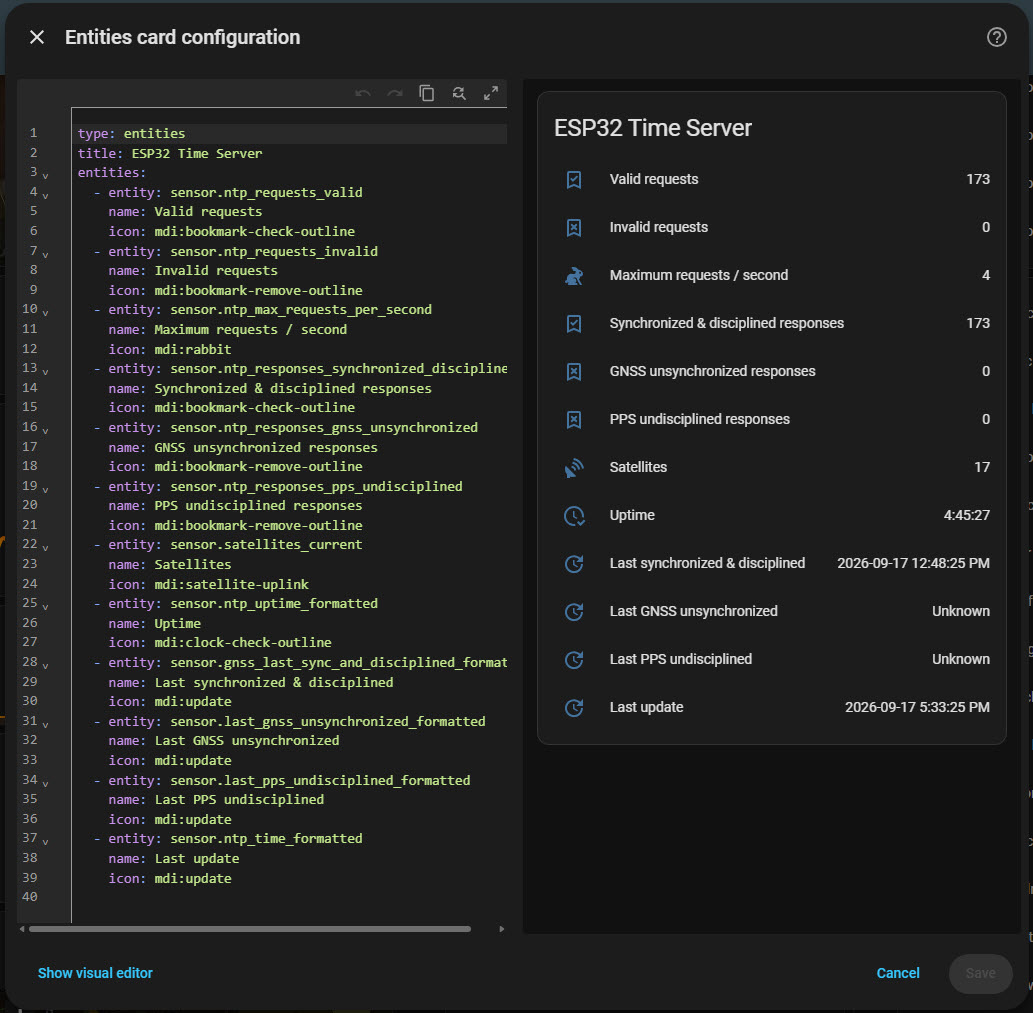
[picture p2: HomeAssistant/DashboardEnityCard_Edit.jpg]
Entities card configuration editor


```yaml
type: entities
title: ESP32 Time Server
entities:
  - entity: sensor.ntp_requests_valid
    name: Valid requests
    icon: mdi:bookmark-check-outline
  - entity: sensor.ntp_requests_invalid
    name: Invalid requests
    icon: mdi:bookmark-remove-outline
  - entity: sensor.ntp_max_requests_per_second
    name: Maximum requests / second
    icon: mdi:rabbit
  - entity: sensor.ntp_responses_synchronized_disciplined
    name: Synchronized & disciplined responses
    icon: mdi:bookmark-check-outline
  - entity: sensor.ntp_responses_gnss_unsynchronized
    name: GNSS unsynchronized responses
    icon: mdi:bookmark-remove-outline
  - entity: sensor.ntp_responses_pps_undisciplined
    name: PPS undisciplined responses
    icon: mdi:bookmark-remove-outline
  - entity: sensor.satellites_current
    name: Satellites
    icon: mdi:satellite-uplink
  - entity: sensor.ntp_uptime_formatted
    name: Uptime
    icon: mdi:clock-check-outline
  - entity: sensor.gnss_last_sync_and_disciplined_formatted
    name: Last synchronized & disciplined
    icon: mdi:update
  - entity: sensor.last_gnss_unsynchronized_formatted
    name: Last GNSS unsynchronized
    icon: mdi:update
  - entity: sensor.last_pps_undisciplined_formatted
    name: Last PPS undisciplined
    icon: mdi:update
  - entity: sensor.ntp_time_formatted
    name: Last update
    icon: mdi:update
```

**Note**: when SYMMETRIC_KEY_AUTHENTICATION_ENABLED and MQTT_DISTINGUISH_AUTHENTICATED_REPORTING_ENABLED are both enabled
replace the following from above:
```
  - entity: sensor.ntp_requests_valid
    name: Valid requests
    icon: mdi:bookmark-check-outline
  - entity: sensor.ntp_requests_invalid
    name: Invalid requests
    icon: mdi:bookmark-remove-outline
```
with:

```
  - entity: sensor.ntp_requests_authenticated_valid
    name: Authenticated valid requests
    icon: mdi:bookmark-check-outline
  - entity: sensor.ntp_requests_authenticated_invalid
    name: Authenticated invalid requests
    icon: mdi:bookmark-remove-outline
  - entity: sensor.ntp_requests_unauthenticated_valid
    name: Unauthenticated valid requests
    icon: mdi:bookmark-check-outline
  - entity: sensor.ntp_requests_unauthenticated_invalid
    name: Unauthenticated invalid requests
    icon: mdi:bookmark-remove-outline
 ``` 

4. Click **Save**. The card will appear on your dashboard displaying last
   published report from the ESP32 Time Server.

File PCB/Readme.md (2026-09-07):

# KiCad PCB Files for ESP32 Time Server

This folder and its sub-folders contain the KiCad files used to create the ESP32
Time Server's PCB.

> **Important:**
>
> **This PCB is only compatible when using the RX, TX, and PPS pin
> configurations used in the ESP32TimeServer v2.3.1 software and earlier.**
>
> In version 2.4, the RX, TX, and PPS pin configurations were changed for better
> forward and backward compatibility between revisions of the ESP32-P4 chip.
>
> In version 2.3.1 and earlier, the following were used:
>
> - ESP32-P4-ETH GPIO16 (TX) connected to the GPS RX pin
> - ESP32-P4-ETH GPIO17 (RX) connected to the GPS TX pin
> - ESP32-P4-ETH GPIO18 connected to the GPS PPS pin
>
> In version 2.4, the pin configurations have been changed to:
>
> - ESP32-P4-ETH GPIO22 (TX) connected to the GPS RX pin
> - ESP32-P4-ETH GPIO21 (RX) connected to the GPS TX pin
> - ESP32-P4-ETH GPIO20 connected to the GPS PPS pin
>
> However, if your setup is running fine in version 2.4 and beyond with the
> original GPIO16, 17, and 18 pin selections, this PCB will still work as long
> as the setting files specify the older pin usage.
>
> If a newer version of the PCB is developed to use the new pins, it will
> eventually be posted here.

The BOM components part numbers needed to order this board via JLCPBC are as
follows:

| Item | Qty | JLCPCB Part Number | Url |
| --- | --- | --- | --- |
| 20 pin socket for ESP32-P4-ETH | 2 | C2905423 | https://jlcpcb.com/partdetail/3175197-KH_2_54FH_1X20P_H85/C2905423 |
| 8 pin socket for GPS | 1 | C2905417 | https://jlcpcb.com/partdetail/3175191-KH_2_54FH_1X8P_H85/C2905417  |
| connector for LCD: | 1 | C566011 | https://jlcpcb.com/partdetail/JST-B4B_PH_K_SGW/C566011 |
| connector for button: | 1 | C5251182 | https://jlcpcb.com/partdetail/JST-B2B_PH_K_SGW/C5251182 |

Note: When I designed the board I didn't think to label the pins for the LCD
connector on the board.

If I ever need more boards I'll fix this, but for now the photo of the board
below has edited onto it the missing pin markings:

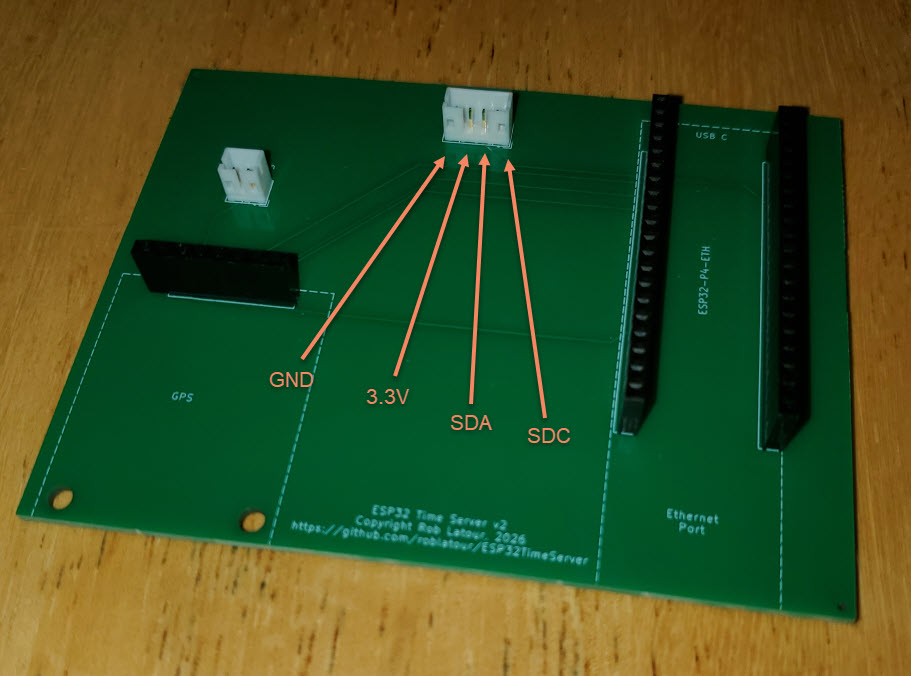
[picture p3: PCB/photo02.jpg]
ESP32 Time Server PCB


Also, when looking at the other photos of the PCB with the components (below)
don't let colour of the wires of the LCD connector cable confuse you. Ideally
they would have been coloured differently. However, I had that pre-wired cable
connector on hand and I just used it.

The pin markings for the external button connector don't matter, as either pin
can be connected to either terminal of the external button.

ESP32 Time Server PCB ESP32 Time Server PCB
ESP32 Time Server PCB ESP32 Time Server PCB
ESP32 Time Server PCB

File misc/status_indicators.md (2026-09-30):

# Default LCD top line display messages and RGB LED meanings:

| Top Line | RGB LED | Meaning |
| --- | --- | --- |
| ESP32 Time Server | Blue | The server is in startup mode |
| ESP32 Time Server | Blue flashing | The server is almost ready, but needs to complete PPS disciplining |
| | | |
| ESP32 Time Server | Green | The server is operating normally |
| ESP32 Time Server[3] | Yellow flashing | There are queued MQTT items |
| ESP32 Time Server[5] | Yellow | PPS missing |
| ESP32 Time Server[6] | Yellow | GNSS missing or invalid |
| ESP32 Time Server[7] | Yellow | GNSS sync stale |
| ESP32 Time Server[8] | Yellow | GNSS has lost its satellite lock |
| ESP32 Time Server[M] | Red flashing | Not connected to the MQTT broker |
| ESP32 Time Server[9] | Red | Communication failure with the GNSS receiver |
| ESP32 Time Server[1] | Red | Ethernet not connected |
| ESP32 Time Server[2] | Red | MQTT setup failed |
| ESP32 Time Server[T] | Red | Transport layer stalled |
| ESP32 Time Server[4] | Red | Sanity check mismatch |
| | | |
| ESP32 Time Server[I] | Orange | IPv4 address not assigned yet preferred |
| ESP32 Time Server[+] | Orange flashing | Load shedding active |
| ESP32 Time Server[*] | White | The server is synchronizing its time |
| ESP32 Time Server's  | Pink | The button is being pressed |

>Note:
>In timekeeping terminology, holdover is the state where a time server continues providing time from its internal
>oscillator after losing its external reference (in this case the GNSS). The device is no longer actively
>synchronized but is "coasting" on its last-known good time.  Holdover mode is not expressly reported on the
>LCD's top line or via the RBB LED as it is implied when the PPS missing, the GNSS missing or invalid, the 
> GNSS sync is stale, or the GNSS has lost its satellite lock.

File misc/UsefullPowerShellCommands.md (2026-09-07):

# Useful Command Prompt Commands

Below, in more detail, are various Command Prompt commands that will allow you
to:

- Provide for Over The Ethernet (OTE) updates
- Test for NTP responses
- Reset the Meinberg drift file (to recreate a new baseline for the use of a
  different time server)

## Notes

In the examples below:

- The device name, `ESP32TimeServer`, is set as `DeviceName` in
  `ESP32TimeServerSettings.h`.
- `x.x.x.x` is the IP address of the ESP32-P4 running the ESP32 time server
  software.

## 1. Over The Ethernet (OTE) Updates

Here are a couple example command line commands which may be used, following a
build, to provide for an Over The Ethernet (OTE) update. The path name which
precedes `ESP32TimeServer.bin` may vary.

```cmd
python tools\espota.py -i ESP32TimeServer.local -p 3232 -P 3232 -a ESP32TimeServerpw -f build-esp32p4-rev-1-3\ESP32TimeServer.bin -r -d
```

or

```cmd
python tools\espota.py -i x.x.x.x -p 3232 -P 3232 -a ESP32TimeServerpw -f build-esp32p4-rev-1-3\ESP32TimeServer.bin -r -d
```

## 2. NTP Test Request (ntpdate) - Linux or Windows (with Meinberg)

Here is a command which may be used for sending a NTP test request on Linux or
Windows (with the Meinberg Network Time Protocol Daemon service for Windows
installed and running):

```cmd
ntpdate -q ESP32TimeServer.local
```

or

```cmd
ntpdate -q x.x.x.x
```

With the output showing, for example:

```text
28 Aug 10:46:21 ntpdate[51120]: Raised to realtime priority class
server 192.168.7.24, stratum 1, offset +0.006410, delay 0.04124
28 Aug 10:46:24 ntpdate[51120]: adjust time server 192.168.7.24 offset +0.006410 sec
```

The `stratum 1` value indicates that the server is a Stratum 1 time source
(directly connected to a reference clock, in this case GNSS). The `offset` value
is the clock offset between the machine issuing the command and the
`ESP32TimeServer.local` device (in the case above approximately 6/1000's of a
second). The `delay` value is the round-trip network delay.

## 3. NTP Test Request (w32tm) - Windows only

If you are using Windows and running the default Windows Time service, here is a
command which may be used for sending NTP test requests (will not work if you
are not using Windows or using the Meinberg Network Time Protocol Daemon service
for Windows):

```cmd
w32tm /stripchart /computer:ESP32TimeServer.local /samples:5 /dataonly
```

or

```cmd
w32tm /stripchart /computer:x.x.x.x /samples:5 /dataonly
```

With the output showing, for example:

```text
Tracking 192.168.7.24 [192.168.7.24:123].
Collecting 5 samples.
The current time is 2026-08-24 8:23:44 AM.
08:23:44, +00.0022650s
08:23:46, +00.0016820s
08:23:48, +00.0016135s
08:23:50, +00.0017035s
08:23:52, +00.0018610s
```

The first number above is the current time. The second number above is the clock
offset between the machine issuing the command and the `ESP32TimeServer.local`
device (in the case above approximately 2/1000's of a second).

## 4. NTP Test Request (sntp) - MacOS

If you are using MacOS, here is a command which may be used for sending an NTP
test request (the `sntp` utility is included with MacOS by default):

```cmd
sntp -d ESP32TimeServer.local
```

or

```cmd
sntp -d x.x.x.x
```

With the output showing, for example:

```text
sntp 4.2.8p15@1.37-o
request 2026-08-24T08:24:01
rec:1715006401.000000 frac:0.000000000
refid: .GNSS.
leap: 0 stratum: 1 rootdelay: 0.000000
response from ESP32TimeServer.local: offset 0.002154, delay 0.040680
```

The offset value shown above is the clock offset between the machine issuing the
command and the `ESP32TimeServer.local` device (in the case above approximately
2/1000's of a second).

## 5. Resetting the Meinberg Drift File

If you are using the
[Meinberg NTP Time Server](https://www.meinbergglobal.com/english/sw/ntp.htm)
and you want to create a new baseline as you are now using a new time server,
then from the Windows Command Prompt with Administrative Privileges you can use
these commands:

```cmd
net stop ntp
del "C:\Program Files (x86)\NTP\etc\ntp.drift"
net start ntp
```

Between 15 minutes to an hour later a new `ntp.drift` file will be created by
the service.

If you don't do this the Meinberg software will automatically recalibrate the
drift file within a few hours.

## 6. NTP Stress Testing Tool

Here is an open source Windows app, written by me, which can be used to stress
test your NTP server.

[TimeServerStressTest](https://github.com/roblatour/TimeServerStressTest)



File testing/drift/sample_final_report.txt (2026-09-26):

Executive Summary
Overall Result: PASS

Test Period: 26 Sep 11:58:30 - 26 Sep 14:58:32

Master server: 192.168.7.24
Reference Server: 192.168.1.24
External source 1: time.nrc.ca
External source 2: 0.ca.pool.ntp.org

Test Duration: 3:00:02
Number of tests: 7

Endpoint Drift Comparison: time.nrc.ca
Master Server
Initial Error: 0.001049
Final Error: 0.000991
Net Endpoint Drift: -0.000058
Trend Slope: -0.000102
Assessment: PASS

Reference Server
Initial Error: 0.001397
Final Error: 0.001256
Net Endpoint Drift: -0.000141
Trend Slope: -0.000040
Assessment: PASS

Endpoint Drift Comparison: 0.ca.pool.ntp.org
Master Server
Initial Error: 0.000959
Final Error: 0.001089
Net Endpoint Drift: 0.000130
Trend Slope: -0.000084
Assessment: PASS

Reference Server
Initial Error: 0.001307
Final Error: 0.001354
Net Endpoint Drift: 0.000047
Trend Slope: -0.000022
Assessment: PASS

Internal Synchronization
Initial Difference: -0.000348
Final Difference: -0.000265
Net Separation Change: 0.000083
Maximum Separation: 0.001407
Trend Slope: -0.000062
Assessment: PASS

External Reference Consistency
Eligible two-source consensus samples: 7
Rejected two-source consensus samples: 0
Average Consensus Value: 0.003785
Average Absolute Disagreement: 0.000117
Maximum Absolute Disagreement: 0.000247
Disagreement Standard Deviation: 0.000086
Rejected Series: None

Findings and Conclusions:
The Master and Reference servers passed the endpoint-drift comparison relative to time.nrc.ca. Their respective endpoint changes were 0.000058 and 0.000141 seconds, within the configured 0.005000-second thresholds.
The Master and Reference servers passed the endpoint-drift comparison relative to 0.ca.pool.ntp.org.
The Master-to-Reference endpoint separation remained within the configured synchronization thresholds.

(review.py version 1.1)

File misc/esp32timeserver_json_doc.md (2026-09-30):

# ESP32 Time Server MQTT JSON Reporting

The ESP32 Time Server's settings file ( `main/ESP32TimeServerSettings.h` ) is
use to enable and configure MQTT reporting.

When MQTT is enabled a JSON message will be published to `<MQTT_TOPIC>/report`
every `MQTT_Reporting_Period` seconds. Other configuration settings determine
the reporting content as described in more detail below.

Additionally, near the end of this document there is a description of 
controlled restart events and an example of a MQTT message for one.

## Example report

```json
{
    "current": {
        "time": "2026-08-30T13:49:53-0400",
        "uptime": 2187,
        "ethernet_up": true,
        "gnss_synchronized": true,
        "gnss_synchronized_indicators": {
            "locked": true,
            "timing": true,
            "gps_valid": true,
            "sync_fresh": true,
            "sanity_check_passed": true
        },
        "pps_disciplined": true,
        "pps_disciplined_indicators": {
            "pps_signals_present": true,
            "discipline_active": true,
            "pps_synchronized": true
        },
        "satellites": 21,
        "memory": {
            "malloc_cap_dma": 115088,
            "free_heap": 154668,
            "minimum_free_heap": 148520,
            "largest_free_8bit_block": 106496
        }
    },
    "queued_messages": {
        "held": 0,
        "discarded": 0
    },
    "this_period": {
        "ethernet_up_secs": 120,
        "pps_pulses": 120,
        "gnss_locked_secs": 120,
        "satellites": {
            "min": 15,
            "max": 23
        },
        "ntp": {
            "requests": {
                "valid": 4,
                "invalid": 0,
                "load_shedding": false,
                "telemetry_dropped": 0,
                "max_per_second": 1
            },
            "responses": {
                "synchronized_and_disciplined": 4,
                "gnss_unsynchronized": 0,
                "pps_undisciplined": 0
            }
        },
        "clients": [
            {
                "address": "192.168.1.1",
                "requests": 2
            },
            {
                "address": "192.168.1.10",
                "requests": 1
            },
            {
                "address": "192.168.1.15",
                "requests": 1
            }
        ],
        "clients_overflown": false
    },
    "historical": {
        "gnss_receiver_last": {
            "synchronized_and_disciplined": "2026-08-30T13:49:33-0400",
            "gnss_unsynchronized": "",
            "pps_undisciplined": ""
        }
    }
}
```

## Always-present sections

### `current`

The `current` object reports the following states at the time the message is
created.

- **`time`**: Local device time in ISO 8601 basic-offset format
  (`YYYY-MM-DDTHH:MM:SS±HHMM`).
- **`uptime`**: Seconds since the ESP32 Time Server booted.
- **`ethernet_up`**: If the ethernet link is currently connected.

  Note: If the Ethernet isn't currently connected this message may be queued for
  later publication depending on the MQTT QOS setting.

- **`pps_active`**: If the PPS-based time discipline is currently working as
  expected.
- **`gnss_synchronized`**: An indicator reporting if the GNSS receiver is
  synchronized.
- **`gnss_synchronized_indicators`** a series of indicators to help identify
  issues should the gnss receiver become unsynchronized.

  Note: While the `gnss_synchronized_indicators` are shown in the example above,
  in practice they will only be present when `gnss_synchronized` is `false`.

- **`pps_disciplined`**: An indicator reporting if the PPS is disciplined.
- **`pps_disciplined_indicators`** a series of indicators to help identify
  issues should the PPS become undisciplined.

  Note: While the `pps_disciplined_indicators` are shown in the example above,
  in practice they will only be present when `pps_disciplined` is `false`.

- **`satellites`**: The number of satellites currently reported by the GNSS
  receiver.

### `this_period`

The `this_period` object reports activity in the current reporting period.
Counters in this object are reset after they are included in a report.

- **`ethernet_up_secs`**: Seconds that the Ethernet link was connected during
  the reporting period.

- **`pps_pulses`**: Number of PPS pulses received during the reporting period.
- **`gnss_locked_secs`**: Seconds that GNSS time lock was active during the
  reporting period.
- **`satellites.min`**: Lowest satellite count observed during the reporting
  period.
- **`satellites.max`**: Highest satellite count observed during the reporting
  period.
- **`ntp.requests.valid`**: Number of valid NTP requests received during the
  reporting period.
- **`ntp.requests.invalid`**: Number of invalid NTP requests received during the
  reporting period.
- **`load_shedding`**: If the server is being overwhelmed with NTP requests
  (in the magnitude of several thousand per second) it may need to actively 
  ignore some of them, if this happened this value will be true, 
  otherwise it will be false. 
- **`telemetry_dropped`**: Number of valid NTP requests whose optional MQTT
  client telemetry event could not be queued, usually because the event queue
  was full during a high request-rate burst. These requests were still received,
  processed, and replied to by the NTP server, and are included in
  `ntp.requests.valid`. Their source addresses and request counts are omitted
  from `this_period.clients`. This field does not affect
  `ntp.requests.max_per_second`, which is measured independently from the NTP
  request count at PPS intervals.
- **`ntp.requests.max_per_second`**: Highest NTP request rate observed in one
  PPS-delimited second during the reporting period.
- **`ntp.responses.gnss_lock`**: Number of NTP responses sent while GNSS time
  lock was available during the reporting period.
- **`ntp.responses.gnss_unlock`**: Number of NTP responses sent without GNSS
  time lock during the reporting period.

## Conditionally included sections

The following objects are included only when their corresponding compile-time
setting is enabled.

### `current.memory`

Included when `MQTT_MEMORY_REPORTING_ENABLED` is `1` (Enabled).

All values are byte counts. `malloc_cap_dma` reports free heap memory that
matches the ESP-IDF DMA allocation capability. `free_heap` is the total
currently free heap, `minimum_free_heap` is the lowest total free heap observed
since boot, and `largest_free_8bit_block` is the largest currently allocatable
8-bit-capable block.

### `queued_messages`

Included when `MQTT_QOS` is set to `1` or `2`. It describes reports queued in
volatile RAM while the MQTT broker was unavailable.

- **`held`**: Number of previously queued reports waiting when this report was
  created.

- **`discarded`**: Number of queued reports discarded since the preceding report
  because the queue reached its capacity. This counter is reset after reporting.

QoS `0` does not queue reports, so this object is omitted.

Please see the ESP32 Time Server's settings file for more information on
MQTT_QOS values and the limitations associated with queueing.

### `this_period.clients` and `this_period.clients_overflown`

Included when `MQTT_CLIENT_REPORTING_ENABLED` is `1` (Enabled).

- **`clients`**: An array of unique NTP client addresses observed during the
  reporting period. Each entry contains `address`, an IPv4 or IPv6 address, and
  `requests`, the number of NTP requests from that address during the period.

- **`clients_overflown`**: This will be set to true when the internal client
  table could not hold every unique client observed during the reporting period.

  Without a TF card installed in the ESP32-P4-ETCH only up to 50 client entries
  that can be held for reporting at the end of the reporting period. Client
  information is held and reported on a first come first serve basis. If more
  than 50 unique clients are active in a reporting period, while their NTP
  requests will be processed, they will not be reported in the MQTT message,
  rather the overflow flag will be set to true and reported as such. This flag
  will be reset after reporting for the next reporting period.

  With a TF card installed the limit to how many client entries can be held for
  reporting is set in the Settings file (with a default of 500).

### `historical`

Included when `MQTT_HISTORICAL_REPORTING_ENABLED` is `1` (Enabled).

under `gnss_receiver_last`:

- **`synchronized_and_disciplined`**: Local timestamp of the when the receiver
  was both synchronized and disciplined.
- **`gnss_unsynchronized`**: Local timestamp of when the GNSS last became
  unsynchronized.
- **`pps_undisciplined`**: Local timestamp of when the PPS last became
  undisciplined.

Historical timestamps use the same format as `current - time` (above). A
timestamp is published as an empty string when no corresponding event time is
available.

### `Symmetric key authentication details`

When both SYMMETRIC_KEY_AUTHENTICATION_ENABLED **and** MQTT_DISTINGUISH_AUTHENTICATED_REPORTING_ENABLED are enabled then use:
 
```json
 "ntp": {
            "requests": {
                "authenticated": {
                    "valid": 4,
                    "invalid": 0
                },
                "unauthenticated": {
                    "valid": 0,
                    "invalid": 0
                },
                "load_shedding": false,
                "telemetry_dropped": 0,
                "max_per_second": 1
            },
```
as a replacement for 
```json
 "ntp": {
            "requests": {
                "valid": 4,
                "invalid": 0,
                "load_shedding": false,
                "telemetry_dropped": 0,
                "max_per_second": 1
            },
```
as shown above.

## Controlled restart messages

Controlled restarts are triggered in specific events:
1. A manual restart was requested via uptime/restart button ("manual_restart")
2. An Over the Ethernet firmware update was requested ("over_the_ethernet_update")
3. There were more consecutive time syncs failures than the allowable threshold permits ("more_than_x_consecutive_time_sync_failures")
4. The time sync update failed the sanity check and the option to reboot for such an event was true ("time_sync_failed_sanity_check")
5. The Ethernet transport layer was stalled (became overwhelmed) while processing incoming requests - usually on a scale of over 10K, or more, requests per second over an extended time frame ("ethernet_transport_stalled")

```json
{
    "event": "controlled_restart",
    "reason": "manual_restart"
}
```

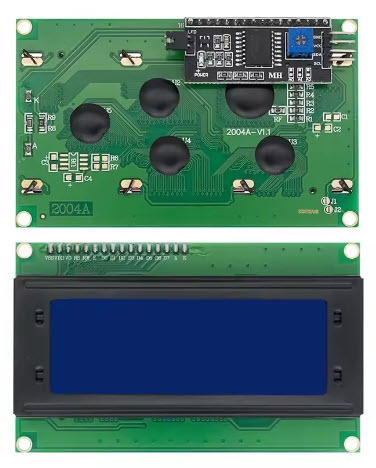
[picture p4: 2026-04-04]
misc/LCD2004_HD44780.jpg

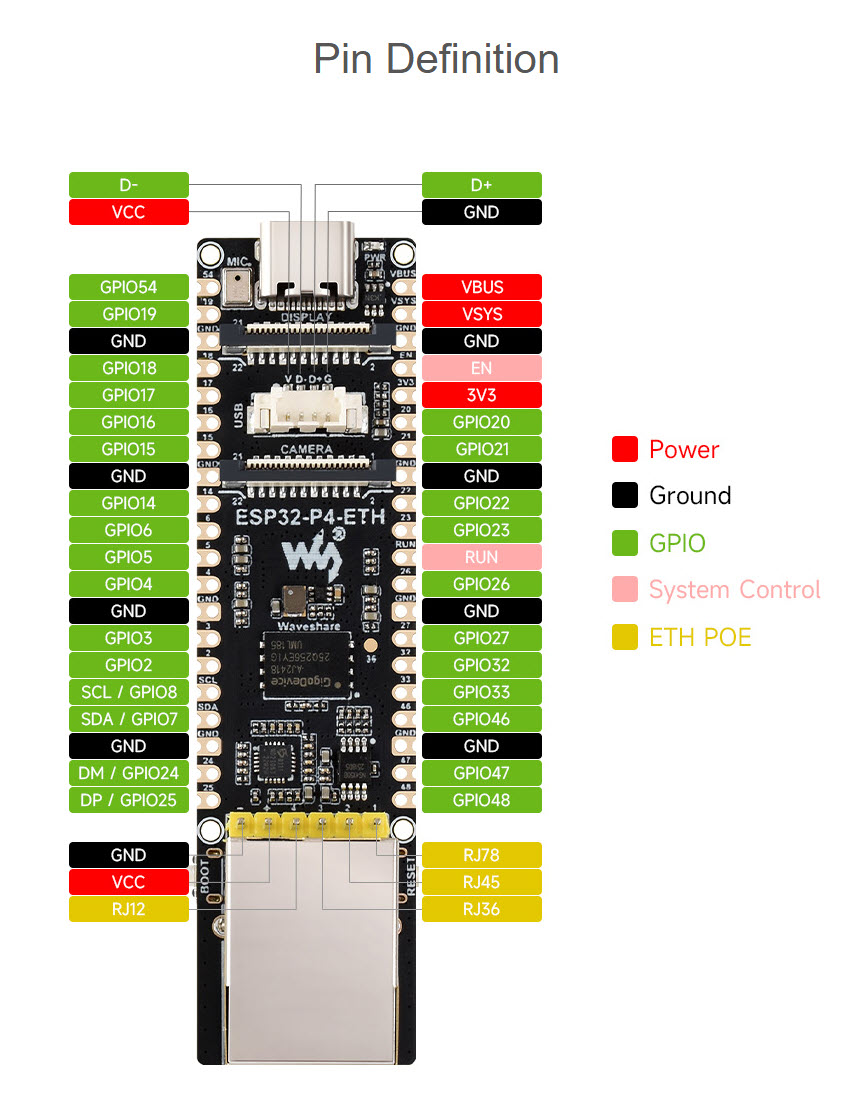
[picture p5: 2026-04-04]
misc/ESP32_P4_ETH.jpg

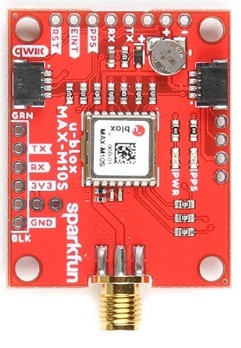
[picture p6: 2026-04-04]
misc/GPS_Top.jpg

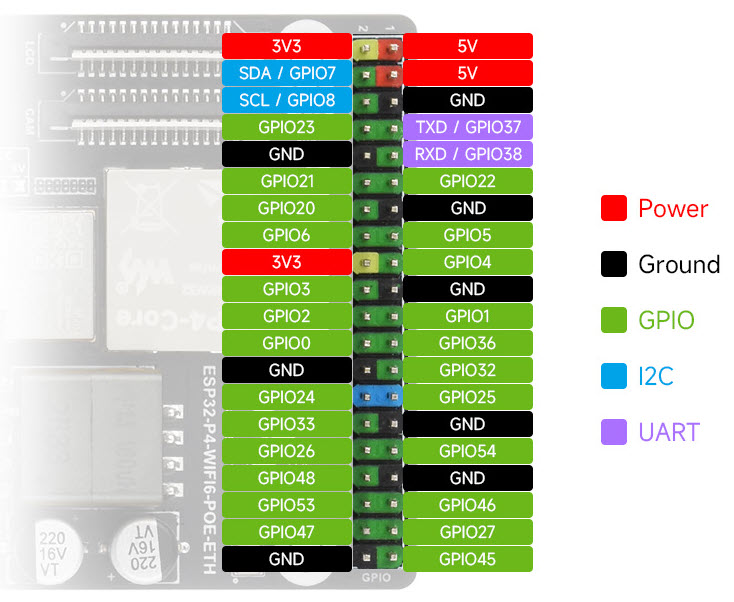
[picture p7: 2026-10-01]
misc/ESP32_P4_WiFi_ETH.jpg

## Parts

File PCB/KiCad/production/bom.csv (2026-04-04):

Designator | Footprint | Quantity | Value | LCSC Part #
BUTTON1 | JST_PH_B2B-PH-K_1x02_P2.00mm_Vertical | 1 | Conn_01x02
GPS1 | PinSocket_1x08_P2.54mm_Vertical | 1 | Conn_01x08_Socket
LCD1 | JST_PH_B4B-PH-K_1x04_P2.00mm_Vertical | 1 | Conn_01x04
LEFT1, RIGHT1 | PinSocket_1x20_P2.54mm_Vertical | 2 | Conn_01x20_Socket

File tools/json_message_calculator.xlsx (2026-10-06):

Setting | Value
Max client entries | 500 | << set to 50 to calculate MQTT_REPORT_SIZE; set to the value of MQTT_TF_Client_Limit to calculate MQTT_MAX_REPORT_SIZE
Component / JSON key or structural token | Emitted JSON / purpose | Max value chars | User value chars (editable) | Repetitions | Fixed bytes | Total bytes | Reduced | Notes
Opening object | { | 0 | 0 | 1 | 1 | 1
current | "current":{ | 0 | 0 | 1 | 11 | 11 |  | includes cr/lf ?
time | "time":"", | 24 | 24 | 1 | 10 | 34
uptime | "uptime":, | 10 | 10 | 1 | 10 | 20
ethernet_up | "ethernet_up":, | 5 | 5 | 1 | 15 | 20
gnss_synchronized | "gnss_synchronized":, | 5 | 5 | 1 | 21 | 26
gnss_synchronized_indicators | "gnss_synchronized_indicators":{ | 0 | 0 | 1 | 32 | 32
locked | "locked":, | 5 | 5 | 1 | 10 | 15
timing | "timing":, | 5 | 5 | 1 | 10 | 15
gnss_valid | "gnss_valid":, | 5 | 5 | 1 | 14 | 19
sync_fresh | "sync_fresh":, | 5 | 5 | 1 | 14 | 19
sanity_check_passed | "sanity_check_passed": | 5 | 5 | 1 | 22 | 27
close indicators | }, | 0 | 0 | 1 | 2 | 2
pps_disciplined | "pps_disciplined":, | 5 | 5 | 1 | 19 | 24
pps_disciplined_indicators | "pps_disciplined_indicators":{ | 0 | 0 | 1 | 30 | 30
pps_signals_present | "pps_signals_present":, | 10 | 5 | 1 | 23 | 28 | * | assume reporting period <= 99999 seconds
discipline_active | "discipline_active":, | 10 | 5 | 1 | 21 | 26 | * | assume reporting period <= 99999 seconds
pps_synchronized | "pps_synchronized": | 10 | 5 | 1 | 19 | 24 | * | assume reporting period <= 99999 seconds
close pps indicators | }, | 0 | 0 | 1 | 2 | 2
satellites | "satellites": | 10 | 3 | 1 | 13 | 16 | * | assume no more that 999 satellites are in view
comma | , | 0 | 0 | 1 | 1 | 1
memory | "memory":{ | 0 | 0 | 1 | 10 | 10
malloc_cap_dma | "malloc_cap_dma":, | 10 | 5 | 1 | 18 | 23 | * | assume values < 99999
free_heap | "free_heap":, | 10 | 5 | 1 | 13 | 18 | * | assume values < 99999
minimum_free_heap | "minimum_free_heap":, | 10 | 5 | 1 | 21 | 26 | * | assume values < 99999
largest_free_8bit_block | "largest_free_8bit_block": | 10 | 5 | 1 | 26 | 31 | * | assume values < 99999
close memory and current | }}, | 0 | 0 | 1 | 3 | 3
queued_messages | "queued_messages":{ | 0 | 0 | 1 | 19 | 19
held | "held":, | 10 | 4 | 1 | 8 | 12 | * | assume less than 9,999 queued messages
discarded | "discarded": | 10 | 4 | 1 | 12 | 16 | * | assume less than 9,999 discarded messages
close queued_messages | }, | 0 | 0 | 1 | 2 | 2
this_period | "this_period":{ | 0 | 0 | 1 | 15 | 15
ethernet_up_secs | "ethernet_up_secs":, | 19 | 7 | 1 | 20 | 27 | * | this number is tied to the reporting period, assume it is a month or less ( there are 2,678,4000 seconds in 31 day month - so 7 digits)
pps_pulses | "pps_pulses":, | 10 | 7 | 1 | 14 | 21 | * | this number is tied to the reporting period, assume it is a year or less ( there are 31,536,000 seconds in a year)
gnss_locked_secs | "gnss_locked_secs":, | 10 | 7 | 1 | 20 | 27 | * | this number is tied to the reporting period, assume it is a year or less ( there are 31,536,000 seconds in a year)
satellites | "satellites":{ | 0 | 0 | 1 | 14 | 14
min | "min":, | 10 | 3 | 1 | 7 | 10 | * | assume no more that 999 satellites
max | "max": | 10 | 3 | 1 | 6 | 9 | * | assume no more that 999 satellites
close period satellites | }, | 0 | 0 | 1 | 2 | 2
ntp | "ntp":{ | 0 | 0 | 1 | 7 | 7
requests | "requests":{ | 0 | 0 | 1 | 12 | 12
valid | "valid":, | 10 | 10 | 1 | 9 | 19 |  | leave high for stress testing over long reporting periods
invalid | "invalid":, | 10 | 10 | 1 | 11 | 21 |  | leave high for stress testing over long reporting periods
load_shedding | "load_shedding":, | 5 | 5 | 1 | 17 | 22
telemetry_dropped | "telemetry_dropped":, | 10 | 10 | 1 | 21 | 31 |  | leave high for stress testing over long reporting periods
max_per_second | "max_per_second": | 10 | 5 | 1 | 17 | 22 | * | assume <= 99,999
close requests | }, | 0 | 0 | 1 | 2 | 2
responses | "responses":{ | 0 | 0 | 1 | 13 | 13
synchronized_and_disciplined | "synchronized_and_disciplined":, | 10 | 10 | 1 | 32 | 42
gnss_unsynchronized | "gnss_unsynchronized":, | 10 | 10 | 1 | 23 | 33
pps_undisciplined | "pps_undisciplined": | 10 | 10 | 1 | 20 | 30
close responses | } | 0 | 0 | 1 | 1 | 1
close ntp | }, | 0 | 0 | 1 | 2 | 2
clients | "clients":[ | 0 | 0 | 1 | 11 | 11
client entry | {"address":"","requests":} | 49 | 49 | 500 | 26 | 37500 |  | See 'Settings' work tab for more information; address = 39 char max (for an IPv6 address) + 10 for request count = 49
client comma | , | 0 | 0 | 499 | 1 | 499
close clients | ], | 0 | 0 | 1 | 2 | 2
clients_overflown | "clients_overflown": | 5 | 5 | 1 | 20 | 25
close this period | }, | 0 | 0 | 1 | 2 | 2
historical | "historical":{ | 0 | 0 | 1 | 14 | 14
gnss_receiver_last | "gnss_receiver_last":{ | 0 | 0 | 1 | 22 | 22
synchronized_and_disciplined | "synchronized_and_disciplined":"", | 24 | 24 | 1 | 34 | 58
gnss_unsynchronized | "gnss_unsynchronized":"", | 24 | 24 | 1 | 25 | 49
pps_undisciplined | "pps_undisciplined":"" | 24 | 24 | 1 | 22 | 46
close receiver | } | 0 | 0 | 1 | 1 | 1
close historical | } | 0 | 0 | 1 | 1 | 1
close root | } | 0 | 0 | 1 | 1 | 1
NUL terminator | NUL | 0 | 0 | 1 | 1 | 1
Future 01 |  | 0 | 0 | 0 | 0 | 0
Future 02 |  | 0 | 0 | 0 | 0 | 0
Future 03 |  | 0 | 0 | 0 | 0 | 0
Future 04 |  | 0 | 0 | 0 | 0 | 0
Future 05 |  | 0 | 0 | 0 | 0 | 0
Future 06 |  | 0 | 0 | 0 | 0 | 0
Future 07 |  | 0 | 0 | 0 | 0 | 0
Future 08 |  | 0 | 0 | 0 | 0 | 0
Future 09 |  | 0 | 0 | 0 | 0 | 0
Future 10 |  | 0 | 0 | 0 | 0 | 0
Future 11 |  | 0 | 0 | 0 | 0 | 0
Future 12 |  | 0 | 0 | 0 | 0 | 0
Future 13 |  | 0 | 0 | 0 | 0 | 0
Future 14 |  | 0 | 0 | 0 | 0 | 0
Future 15 |  | 0 | 0 | 0 | 0 | 0
Future 16 |  | 0 | 0 | 0 | 0 | 0
Future 17 |  | 0 | 0 | 0 | 0 | 0
Future 18 |  | 0 | 0 | 0 | 0 | 0
Future 19 |  | 0 | 0 | 0 | 0 | 0
 |  | 434 | 343 |  | 900
Grand total | Maximum JSON message bytes (based on Max client entries in Settiings worktab ) (including NUL) |  |  |  |  | 39166
Notes: | C/D are character capacities; formulas use editable D values. Future rows are reserved for future use but includeed in the grand total.
https://github.com/roblatour/ESP32TimeServer/tree/main/misc

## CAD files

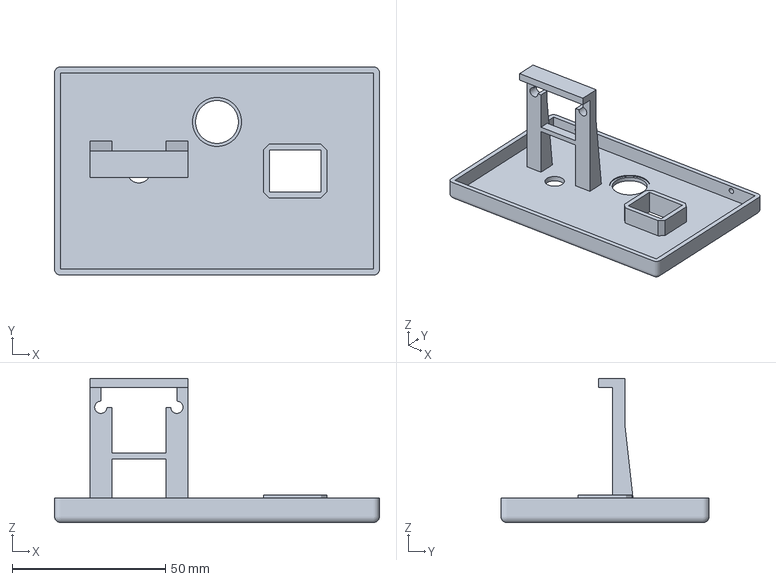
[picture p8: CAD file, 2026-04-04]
3D printable case/Back Olimex.3mf
106.0 x 68.0 x 47.0 mm

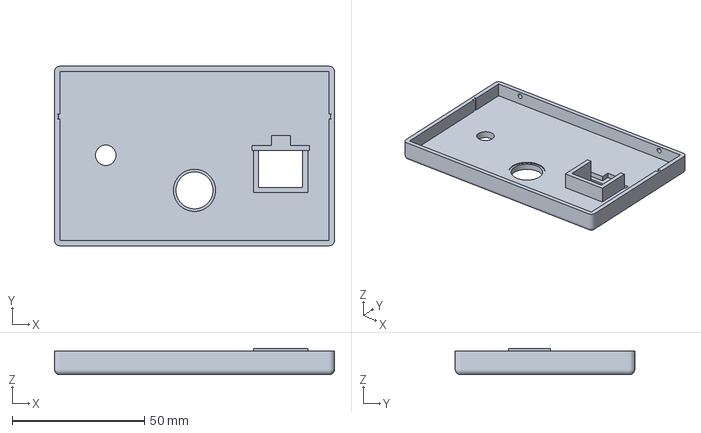
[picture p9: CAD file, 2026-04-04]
3D printable case/Back ESP32-P4-ETH-PCB-NoUSB.3mf
106.0 x 68.0 x 10.0 mm

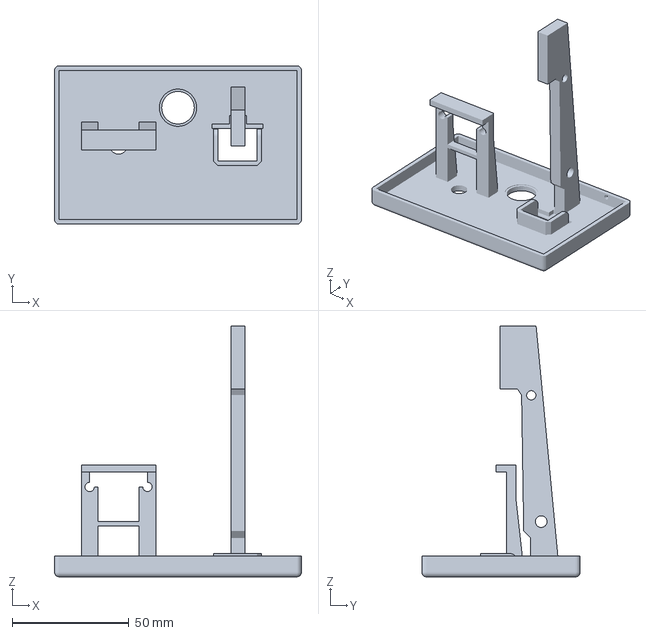
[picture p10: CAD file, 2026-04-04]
3D printable case/Back ESP32-P4-ETH-NoUSB.3mf
106.0 x 68.0 x 107.6 mm

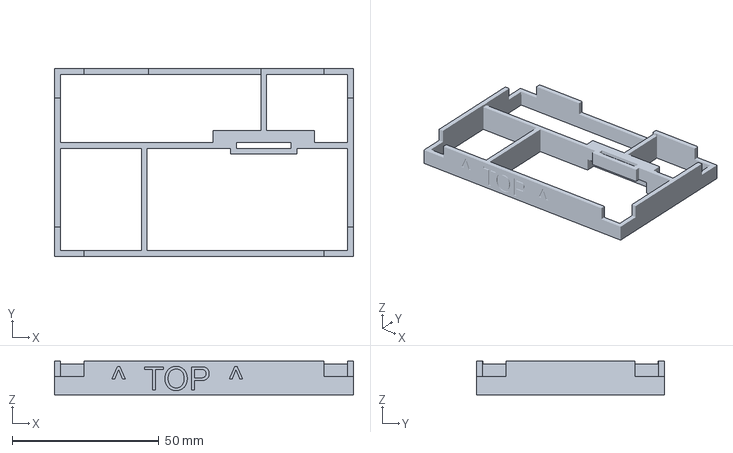
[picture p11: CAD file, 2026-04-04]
3D printable case/Brace Olimex.3mf
102.0 x 64.0 x 11.5 mm

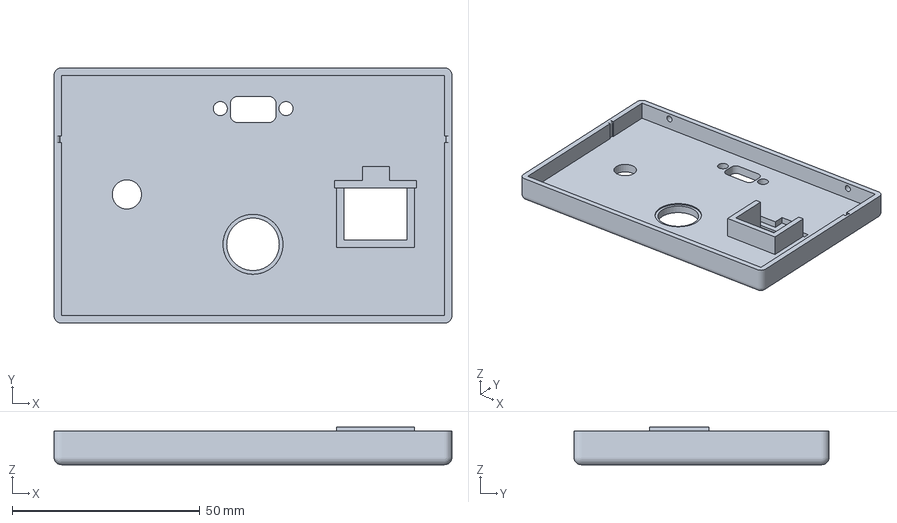
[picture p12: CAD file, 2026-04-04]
3D printable case/Back ESP32-P4-ETH PCB.3mf
106.0 x 68.0 x 10.0 mm

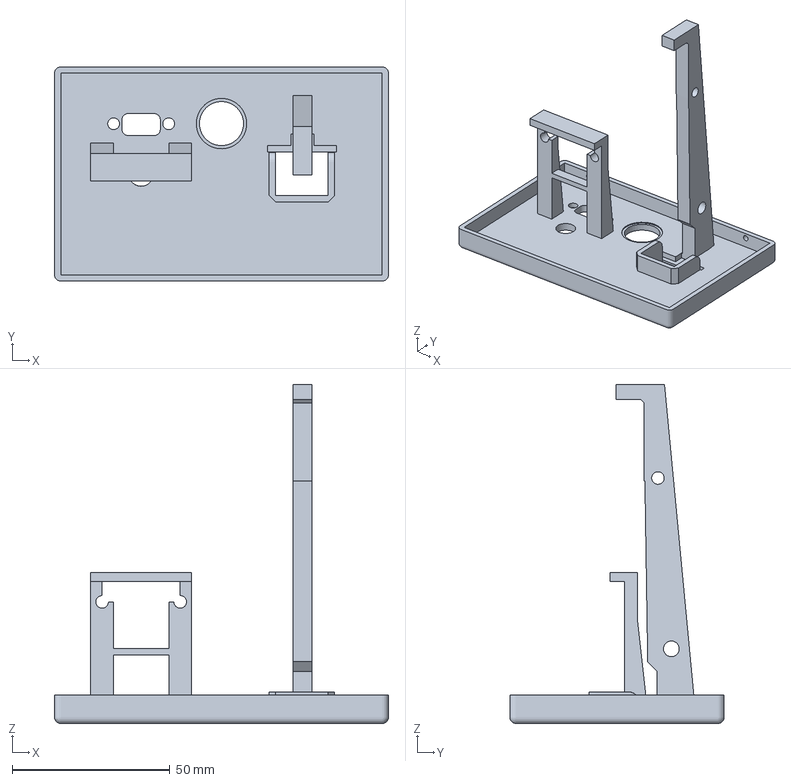
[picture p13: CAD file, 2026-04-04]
3D printable case/Back ESP32-P4-ETH-USB.3mf
106.0 x 68.0 x 107.6 mm

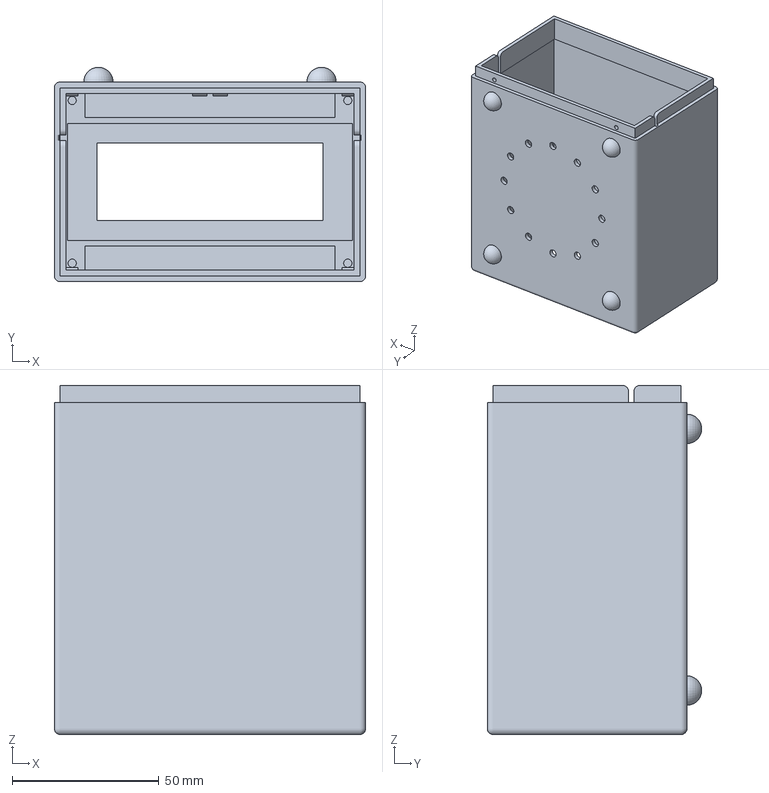
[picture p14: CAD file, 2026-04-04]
3D printable case/Case.3mf
106.0 x 73.0 x 118.8 mm

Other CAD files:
3D printable case/Back ESP32-P4-ETH PCB.stl
3D printable case/Back ESP32-P4-ETH-NoUSB.stl
3D printable case/Back ESP32-P4-ETH-PCB-NoUSB.stl
3D printable case/Back ESP32-P4-ETH-USB.stl
3D printable case/Back Olimex.stl
3D printable case/Brace Olimex.stl
3D printable case/Case.stl

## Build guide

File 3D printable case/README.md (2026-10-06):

# 3D Print models for the ESP32 Time Server project

[ESP32TimeServer](https://github.com/roblatour/ESP32TimeServer) project

Copyright Rob Latour, 2026

## Below you will find some 3D printed models that can be used with this project

The first grouping below are models which use the Waveshare ESP32-P4-ETH dev
board combined with the recommended SparkFun GNSS Receiver, with additional
options for the ESP32-P4-ETH's POE module, an LCD screen, and/or a uptime/reset
button.

The second grouping below includes models which are being shared by other users
of this  
project. If you have a model you would like to share, please just open a github
issue and let me know.

## Group 1

### For ESP32-P4-ETH (with or without the POE module) + SparkFun GNSS Receiver builds, including optional LCD and/or uptime/reset button support

### Fusion 360 Source file

The Fusion 360 source code containing the models for all 3D print files
identified below:

`ESP32 Time Server enclosure.f3z`

### 3D Print Files included

The following 3D print files are include for each of the enclosure parts listed
below:

1. .stl file
2. (PRUSA Slicer) .3mf file
3. (PRUSA Slicer) GCode file (using PTEG)

### Case

The case (filename Case) is designed to accommodate the following:

- [Waveshare ESP32-P4-ETH development board (with or without a POE Hat)](https://www.waveshare.com/esp32-p4-eth.htm)

  or

  Olimex ESP32-ETH-POE (Revision B) (discontinued)

- [Sparkfun Max-M10s GPS module](https://www.sparkfun.com/sparkfun-gnss-receiver-breakout-max-m10s-qwiic.html)

- [an LCD 2004 screen](https://www.aliexpress.com/item/1005006829045609.html)

- [an optional USB C cable connector](https://www.aliexpress.com/item/1005006584965187.html)
  (right angle connector)

- [button](https://www.aliexpress.com/item/1005004066257419.html)

### Backing

The particular case back needed depends on the configuration choosen.

The Backing file naming convention is as follows:

Fileaname contains: `Back`

Filename contains either: `ESP32-P4-ETH` or `OLIMEX` to indicate which
development board it accommodates.

Filename contains either: USB or NoUSB to indicate if an opening for the USB
connector is included in the print (see note below).

Filename contains PCB to indicate the back is designed to accommodate the PCB.

### Brace

The Olimex enclosure requires the printing of the Brace Olimex file.

The ETH-P4-ETH enclosure does not require a separate brace file as the brace is
built into the back.

**Notes:**

1. The ESP32-P4-ETH may be powered either by POE or USB-C - BUT MUST NOT BE
   POWERED BY BOTH AT THE SAME TIME.

2. If using the ESP32-P4-ETH with the POE hat the USB cable should be connected
   only when the Ethernet cable is not coming from an POE powering device (such
   as a POE switch or POE injector).

3. The USB-C cable may be use to get console log outputs from the ESP32-P4-ETH
   board, or to flash it. However, flashing may also be achieved via an Over The
   Ethernet update.

4. The Olimex related models above were designed to accommodate the Olimex
   revision B board - newer revisions may not work.

5. The Olimex board also requires the printing of the Olimex brace file.

6. A USB-C cable connector option is not available for the Olimex board
   configuration.

## Group 2 - other user builds using various combinations of hardware

2.1 with thanks to github and printables user Duglum:

Various case designs for use with the ESP32-P4-ETH and
ESP32-P4-WIFI6-ETH dev boards (with and without the POE options)
(without an LCD or an uptime/Reset button)

<https://www.printables.com/model/1821834-case-for-waveshare-esp32-p4>

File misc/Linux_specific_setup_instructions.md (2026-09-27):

## Setup - **Linux (Debian 13)**

**Setup Step 0 - Prerequisites**

There are a few things you need before you can begin to set up your ESP32TimeServer under Linux.

First, remember in Linux, everything is case-sensitive: Hello, hello, HeLlO, hellO are 4 completely different items.  This is very important when using the command line.  If something does not work, check to make sure you have the case correct.

When you installed ESP-IDF and associated Tools, Python should have been installed as a prerequisite.  Note that for Linux, you are installing the ESP-IDF Installation Manager (EIM) when you follow the instructions at the ESP-IDF Linux link.  Unless you are on a system that does not have a graphical environment installed, install the version with both GUI and CLI.  Before you can use ESP-IDF (and it's tools) you need to set up the environment for your user.  This is where the GUI comes in handy.  After installing EIM, run it, and choose 'Start Installation' under 'New Installation'.  Easy Installation is recommended - it will download and install all the necessary components and set up the Python virtual environment properly.  Kick it off, grab a coffee, and wait for it to complete. When it is done, you can close the EIM window.  These instructions assume you did the default install, which puts the installation in ~/.espressif/v6.1/esp-idf/.  If you chose to put it elsewhere, you will need to know the path and make the appropriate changes to the compile and flash commands later in these instructions. For the installation examples here, the username is 'user' and the host is 'shop'.

While configuration and flashing of the ESP32 Time Server does not require root privileges, your user does have to be a member of the dialout group.  This is the group with permissions to the USB Serial interface on the ESP32.  If you try to flash the ESP32 Time Server and get an access error - double check your group membership:

```
grep -i dialout /etc/group
```
```
dialout:x:20:user  <- You should see your username here!
```

Please, for the love of all that is Linux, do not run as the root user or run everything under root privileges.  It is a very bad idea(tm)!  Have your user added to the dialout group.  It makes life easier (and safer).

In addition to ESP-IDF and it's associated tools (and dependencies), you will need GIT installed on your system.

Once you have met these requirements, you are ready to go forth and conquer!

**Setup Step 1 - Download**

Create a working directory and enter it:
```
mkdir ESP32TimeServer
```
```
cd ESP32TimeServer
```

Clone the git repository:
```
git clone –-recursive https://github.com/roblatour/ESP32TimeServer
```

Change into the cloned repository directory:
```
cd ESP32TimeServer
```

Perform a submodule update:
```
git submodule update --init --recursive
```

**Setup Step 2 - Configuration**

This is the same for Linux and Windows.  Edit using a text editor either from the command line (vi, vim, emacs, nano, pico, etc.) or from the gui (gedit, etc.)

**Setup Step 3 - Build**

Before you can build, you must set up the ESP-IDF environment for this project.

Install ESP-IDF for this project:
```
~/.espressif/v6.1/esp-idf/install.sh
```

You must source the export.sh script, you cannot simply execute it.  Make sure you replace 'user' with your actual user name:
```
source /home/user/.espressif/v6.1/esp-idf/export.sh
```

The message about outdated tools in the system is not a concern, unless you are getting low on disk space.  Then, follow the instructions in the message.

Remove the existing sdkconfig file. This will throw an error if the file is not there, it is safe to ignore the error.
```
rm sdkconfig
```

Use the appropriate build statement, based on your specific ESP32-O4 module:

For older ESP32-P4 modules with revisions prior to version 3.0 (including the Waveshare ESP32-P4-ETH):
```
idf.py -D SDKCONFIG_DEFAULTS="sdkconfig.defaults;config/esp32p4_rev_pre_v3.defaults" set-target esp32p4 build
```

For ESP32-P4 modules at revision 3.0:
```
idf.py -D SDKCONFIG_DEFAULTS="sdkconfig.defaults;config/esp32p4_rev_v3_0.defaults" set-target esp32p4 build
```

For ESP32-P4 modules at revision 3.1 and above (including the WaveShare ESP32-P4-WIFI6-POE-ETH):
```
idf.py -D SDKCONFIG_DEFAULTS="sdkconfig.defaults;config/esp32p4_rev_v3_1.defaults" set-target esp32p4 build
```

**Setup Step 4 - Flash**

Before you can flash the ESP32, you need to find out what port Linux knows it as.  /dev/ttyACM0 is generally a good assumption, but it is also easy to find.  Look in the /dev directory for devices that are in the dialout group.  Devices that start with ttyS are serial ports, you probably do not want those.  This example is from my system:
```
ls -al /dev | grep -i dialout

crw-rw----   1 root dialout 166,     0 Sep 15 21:34 ttyACM0
crw-rw----   1 root dialout   4,    64 Sep 13 22:03 ttyS0
crw-rw----   1 root dialout   4,    65 Sep 13 22:03 ttyS1
crw-rw----   1 root dialout   4,    66 Sep 13 22:03 ttyS2
crw-rw----   1 root dialout   4,    67 Sep 13 22:03 ttyS3
```

/dev/ttyACM0 is the port on my machine.  We will use this for flashing.  Note that this command does two things - first, it flashes the code to the ESP32-P4.  Second, it opens a monitor so you see console messages when the code executes after flashing.
```
idf.py -p /dev/ttyACM0 flash monitor
```

The monitor is opened when you see this line:
```
Executing action: monitor
```

Shortly after, you will begin to see the console messages.  These lines start with an I (informational), W (warning), or E (error) based on the message type.  Not all error messages are fatal - if you enable MQTT but do NOT install a micro-SD card, you will see errors when the system attempts to initialize the (non-existent) card.  This does not affect operation, other than the MQTT queueing, as described elsewhere.

When you see a line similar to:
```
I (585) main_cpp: ******************* Application Startup *******************
```

this indicates the ESP32-P4 has booted and is now running the code flashed to it.  Unless you have DEBUG enabled, you will eventually see lines similar to:
```
I (53834) main_cpp: ***********************************************
I (53835) main_cpp: * Open for business: 2026-09-16T20:51:20-0400 *
I (53836) main_cpp: ***********************************************
W (53841) main_cpp: DEBUG_ENABLED is disabled in the settings file; this will be the last console message from main_cpp
I (53852) main_task: Returned from app_main()
```

Congratulations.  Your NTP server is up and running!

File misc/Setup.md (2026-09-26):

# Using the ESP32 Time Server on Your Network

This guide explains how to configure your network or individual devices to use
the **ESP32 NTP Stratum 1 Time Server** as their time source.

---

## Connect the ESP32 Time Server to your network

For optimal results the ESP32 Time Server should be connected as directly to
your primary router as possible.

Connecting the ESP32 Time Server behind several layers of switches may degrade
its effectiveness.

## Assign a Static IP Address

Before pointing any client at the ESP32 Time Server, it should have a **fixed,
reserved IP address** on your network so that its address never changes after a
DHCP lease renewal.

The easiest way to do this is through a **DHCP reservation** (sometimes called a
static DHCP binding) on your router or firewall, keyed on the ESP32's MAC
address.

> **Finding the IP address**
>
> Once the ESP32 Time Server boots and connects to the network:
>
> - If an **LCD screen is connected**, the assigned IP address is displayed on
>   the screen.
> - If **no LCD is configured**, the IP address is printed to the serial console
>   log (visible via `idf.py monitor` or any serial terminal at 115200 baud).

Note this IP address — it is needed for all of the configuration steps below.

---

## (Optional) Setup of Symmetric-key Authentication

For more information, please see [this documentation](\misc\symmetric_key_authentication_setup.md)

---

## Option A — Port forwarding from a network router to ESP32TimeServer (Network-Wide Setup)

If your network router supports port forwarding then it will most likely be possible to redirect all NTP requests from your internal network directly to the ESP32TimeServer.  In short, redirecting all UDP port 123 traffic to the IP address of the ESP32TimeServer allows it to respond directly, as a Stratum 1 server, to all NTP requests from your internal network.

In this setup the ESP32TimeServer acts as the sole NTP server on your system.  Also, its MQTT reporting provides insights into which devices request NTP update, when and how often.

On the down side, this setup makes the ESP32TimeServer a single point of failure with respect to devices on your internal network getting time updates.  If ESP32TimeServer fails to maintain a satellite fix beyond its sync period, or has other problems, then it will fall back to being as Stratum 16 sever meaning the quality of its time data is undefined. Furthermore if there is a power or network communications loss local to the ESP32TimeServer then NTP requests on your network will go unanswered.

---

## Option B — Using a Network Router's Time Service (Network-Wide Setup)

Using a Router's Network Time Service allows you to set up ESP32TimeServer as sole, primary, or secondary Time Server sources.  In this option your Network Router gets its time from (usually) Stratum 2 Time Servers, manages them, and delivers Stratum 3 quality time to devices on your network.

However, if ESP32TimeServer is identified as a source to your Network Router's time service, then it can use ESP32TimeServer as a Stratum 1 time server, and deliver Stratum 2 quality results to you network devices.

This approach allows fall backups - for example: ESP32TimeServer and Internet NTP pools can be all be both used as source and the Network Router's Time service.  The Network Router's Time service can then prioritize the delivery of ESP32TimeServer Stratum 1 based results, but failing that can fall back to using the Internet NTP pools.

Additionally, on the plus side, the Router's time service usually allows you to view  various time server health indicators.

However, unfortunately as an additional trade off in this setup, the ESP32TimeServer will identify only one client in its MQTT reporting - the Network Router.

Here are some further setup examples:

### OPNsense

OPNsense includes a built-in NTP service that can be pointed at the ESP32 Time
Server so that OPNsense itself syncs to it and then acts as an NTP server for
the rest of the LAN.

1. Log in to the OPNsense web interface.
2. Navigate to **Services → Network Time → General**.
3. In the **Time servers** field, replace any existing entries with the IP
   address of the ESP32 Time Server (e.g., `192.168.1.50`).
4. Set **NTP Orphan Mode** stratum to a value higher than 1 (e.g., `12`) so that
   OPNsense only falls back to its own clock as a last resort.
5. Under the **Interface** section, ensure the NTP service is listening on the
   **LAN** interface (and any other internal interfaces you want to serve).
6. Click **Save** and then **Apply**.
7. Navigate to **Services → Network Time → Status** to confirm OPNsense has
   synchronised to the ESP32 Time Server (it should appear as the active peer at
   stratum 1).

---

### pfSense

pfSense likewise ships with an NTP daemon that can be configured to use the
ESP32 Time Server as its upstream reference.

1. Log in to the pfSense web interface.
2. Navigate to **Services → NTP**.
3. In the **Time Server** list, remove any existing entries and add the IP
   address of the ESP32 Time Server (e.g., `192.168.1.50`). Select **Prefer**
   for this entry.
4. Under **NTP Interface(s)**, check the **LAN** interface (and any additional
   internal interfaces).
5. Set the **Orphan Tier** (under the Clock discipline section) to a value
   higher than 1 (e.g., `12`).
6. Click **Save**.
7. Navigate to **Status → NTP** to confirm pfSense has synchronised with the
   ESP32 Time Server at stratum 1.

This will enable you to view ESP32TimeServer health indicators from the OPNSense/PFSense network status windows and set up alternative internet NTP Servers/Pools to use as fallbacks.  On the down side, in ESP32TimeServer MQTT reporting all traffic
will appear to come from just your router (which is consolidating all the requests).

---

## Option C — Per-Device Setup

If a network-wide change is not possible or desired, each device can be
configured individually to point directly at the ESP32 Time Server's IP address.

---

### Windows — Meinberg NTP Daemon (Recommended)

Windows ships with its own time sync service (`W32tm`), but its accuracy and
reliability are limited. The **Meinberg NTP package** installs a proper `ntpd`
service — the same reference implementation used on servers worldwide — and is
the recommended approach for Windows systems.

#### Download

1. Open a browser and go to:
   [https://www.meinbergglobal.com/english/sw/ntp.htm#ntp_stable](https://www.meinbergglobal.com/english/sw/ntp.htm#ntp_stable)
2. Download the current stable installer — look for the section **"NTP for
   Current Windows Versions (Windows XP and later), with IPv6 support"** and
   download `ntp-4.2.8p18a2-win32-setup.exe` (or the latest version shown on the
   page).
3. Optionally verify the SHA256 checksum of the downloaded file against the
   `.sha256sum` file linked on the same page.

#### Install

1. Right-click the downloaded installer and select **Run as administrator**.
2. **Step 1 — Program folder:** Accept the default or choose a custom
   installation path, then click **Next**.
3. **Step 2 — Components:** Leave all components checked (NTP Service, NTP
   Documentation, etc.) and click **Next**.
4. **Step 3 — Initial configuration:** Select **"Use a public NTP time server"**
   (you will replace this with the ESP32 server address after installation) and
   click **Next**.
5. **Step 4 — Service settings:** Select **"Use System Account"** (recommended)
   and click **Next**.
6. Click **Install** to complete the installation. The NTP service will be
   installed and started automatically.

#### Configure to Use the ESP32 Time Server

After installation, edit the NTP configuration file to point to the ESP32 Time
Server:

1. Open **Notepad** (or any text editor) **as Administrator**.
2. Open the file `C:\Program Files (x86)\NTP\etc\ntp.conf` (or
   `C:\Program Files\NTP\etc\ntp.conf` depending on your system).
3. Find any existing `server` or `pool` lines and replace them with the IP
   address of your ESP32 Time Server. For example:

   ```plaintext
   server 192.168.1.50 iburst prefer
   ```

   Replace `192.168.1.50` with the actual IP address of your ESP32 Time Server.

4. Save the file.
5. Restart the NTP service: open **Services** (`services.msc`), find **NTP
   Daemon**, right-click it, and select **Restart**. Alternatively, run the
   following in an **Administrator Command Prompt**:

   ```cmd
   net stop ntpd
   ```
   ```cmd
   net start ntpd
   ```

#### Verify

Open an **Administrator Command Prompt** and run:

```cmd
ntpq -p
```

After a minute or two the output should show the ESP32 Time Server's IP address
with an asterisk (`*`) next to it, indicating it is the active synchronisation
source. The `stratum` column should read `1`.

You can also use the **NTP Time Server Monitor** (installed alongside the
daemon) to view synchronisation status graphically.

---

### Linux

Most Linux distributions use either `systemd-timesyncd` (simple, default on many
distros) or a full `ntpd` / `chrony` installation.

#### Option 1 — systemd-timesyncd (simple, most desktop distros)

1. Edit the timesyncd configuration file as root:

   ```bash
   sudo nano /etc/systemd/timesyncd.conf
   ```

2. Add or update the `NTP=` line under `[Time]` with the ESP32 Time Server's IP
   address:

   ```ini
   [Time]
   NTP=192.168.1.50
   ```

3. Save the file, then restart the service:

   ```bash
   sudo systemctl restart systemd-timesyncd
   ```

4. Verify synchronisation:

   ```bash
   timedatectl status
   ```

   The output should show `NTP service: active` and
   `System clock synchronized: yes`.

#### Option 2 — chrony (more accurate, recommended for servers)

1. Install chrony if not already present:

   ```bash
   # Debian / Ubuntu
   sudo apt install chrony
   ```
   ```bash
   # Fedora / RHEL / CentOS
   sudo dnf install chrony
  ```

2. Edit the chrony configuration:

   ```bash
   sudo nano /etc/chrony.conf
   ```

3. Comment out or remove existing `pool` / `server` lines and add:

   ```bash
   server 192.168.1.50 iburst prefer
   ```

4. Save and restart chrony:

   ```bash
   sudo systemctl restart chronyd
   ```

5. Verify:

   ```bash
   chronyc tracking
   ```
   ```bash
   chronyc sources -v
   ```

   The ESP32 Time Server should appear with a `*` indicating it is the selected
   source at stratum 1.

#### Option 3 — ntpd

1. Install ntp if not already present:

   ```bash
   # Debian / Ubuntu
   sudo apt install ntp
   ```
   ```bash
   # Fedora / RHEL / CentOS
   sudo dnf install ntp
   ```

2. Edit `/etc/ntp.conf`:

   ```bash
   sudo nano /etc/ntp.conf
   ```

3. Replace existing `pool` / `server` lines with:

   ```bash
   server 192.168.1.50 iburst prefer
   ```

4. Restart ntpd:

   ```bash
   sudo systemctl restart ntp
   ```

5. Verify after a minute:

   ```bash
   ntpq -p
   ```

   The ESP32 Time Server should show with an asterisk (`*`) at stratum 1.

---

### macOS (Apple)

macOS uses its own NTP client, configurable via the **Date & Time** system
settings or the command line.

#### Graphical (System Settings)

1. Open **System Settings** (macOS Ventura and later) or **System Preferences**
   (macOS Monterey and earlier).
2. Navigate to **General → Date & Time** (Ventura/Sonoma) or **Date & Time**
   (Monterey and earlier).
3. Unlock the pane by clicking the padlock and entering your administrator
   password.
4. Ensure **Set date and time automatically** is enabled.
5. In the NTP server field, replace the existing value (e.g., `time.apple.com`)
   with the IP address of the ESP32 Time Server, for example:

   ```plaintext
   192.168.1.50
   ```

6. Press **Enter** / **Return** to confirm.

macOS will now synchronise to the ESP32 Time Server.

#### Command Line

You can also configure the NTP server from the terminal:

```bash
# Set the NTP server
sudo systemsetup -setnetworktimeserver 192.168.1.50
```
```bash
# Enable network time sync
sudo systemsetup -setusingnetworktime on
```
```bash
# Verify
sudo systemsetup -getnetworktimeserver
```

To force an immediate sync:

```bash
sudo sntp -sS 192.168.1.50
```

---

## Validating Accuracy

Once configured, you can cross-check the accuracy of your system clock against
internet references using [https://time.is](https://time.is). A well-configured
Stratum 1 source backed by GPS with PPS should keep your systems within a few
milliseconds of true UTC.

---

## Option D — A Hybrid Approach

Network Routers such as OPNSense and PFSense may be setup as described in Option B above, with individual devices set up to point direct to the ESP32TimeServer's IP address following the steps in Option C.

This give the ability to mix and max the pros and cons of the options above to suite your needs.

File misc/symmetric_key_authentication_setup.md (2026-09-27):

# Setting up the ESP32TimeServer and its clients for symmetric-key authentication

## What is symmetric-key authentication (and what is it not)

Symmetric-key authentication lets NTPv4 clients and the server verify time packets using a shared secret. This helps ensure the client is getting its time from the right server. However, it is 
not a secured protocol as it does not encrypt time traffic or hide the secret from anyone who can read the key files or firmware. Accordingly, its use is targeted for the environments where there is not a concern related to time server spoofing. It works on NTPv4 requests, but not older NTP versions. Also, within ESP32TimeServer it is not an access-control requirement: clients without a key can still receive unauthenticated time responses.  However, clients requesting authenticated time responses with a missing, outdated, or incorrect 
shared secret will be out of luck.  

## Compatibility

ESP32TimeServer supports the symmetric-key NTPv4 authentication implementations of [Meinberg](https://www.meinbergglobal.com/english/sw/ntp.htm) (Windows) and [Chrony](https://chrony-project.org/download.html) (Linux).

W32Time (Windows) and macOS's built-in automated time service (`timed` on modern macOS) do not support symmetric-key NTPv4 authentication, and thus are not supported.

## Set up ESP32TimeServer

1. Set `SYMMETRIC_KEY_AUTHENTICATION_ENABLED` to `1` in `main/ESP32TimeServerSettings.h`.
2. In `main/ESP32TimeServerSettingsSecret.h` contains the symmetric-key authentication key ids and secrets in 
the form `{key_id, "key_value"}`. There must be between one and four such entries defined. If there are multiple entries, they should be unique. A `key_id` must be from 1 to 65535 and unique. `key_value` (the secret) must contain exactly 32 alphanumeric characters. Multiple clients may use the same symmetric-key authentication key ids and secrets.

1. Generate a new random 32-character alphanumeric secret for each key ID. The PowerShell script below outputs a series of characters which can be placed between the quotes in `key_value` field:

   ```powershell
   $alphabet = 'ABCDEFGHIJKLMNOPQRSTUVWXYZabcdefghijklmnopqrstuvwxyz0123456789'.ToCharArray()

   $randomNumberGenerator = [System.Security.Cryptography.RandomNumberGenerator]::Create()
   $characters = [char[]]::new(32)
   $randomByte = [byte[]]::new(1)
   $limit = 256 - (256 % $alphabet.Count)

   for ($index = 0; $index -lt $characters.Length; $index++) {
      do {
         $randomNumberGenerator.GetBytes($randomByte)
      } while ($randomByte[0] -ge $limit)
      $characters[$index] = $alphabet[$randomByte[0] % $alphabet.Count]
   }
   $randomNumberGenerator.Dispose()

   -join $characters
   ```

   Example output to copy and paste into `key_value` (without quotes):
   ```text
   V04ORr3XZwSzO06MUeObebAeJ3Yn0qyo
   ```

   Place the output inside the quotes of the corresponding `symmetric_keys` entry.
   Do not commit settings containing live keys to a public repository. Limit
   access to the settings header, firmware image, build output, and client key
   files to trusted administrators. The secret is recoverable from firmware and
   build materials and files on client systems, so it is not a protection against
   extraction.

2. Build and flash the selected ESP32-P4 board configuration.

3. When the server displays its 'Open for business' message in the console log,
   the client-specific key-file entry will be visible ( a few lines above the `Open 
   business` message) as `Authorization key(s) for use with Meinberg/Chrony ...`. 
   The content lines differ only in their client-file encoding. 
   Treat these console log values as shared secrets: do not publish, retain, or 
   transmit them insecurely.

The key settings are compiled into the application and are not stored in NVS. A
reset-button GNSS-state cleanup does not alter it, but flashing an image built
without that key does. Keep an encrypted, access-controlled backup outside the
repository.

### Add, rotate, and revoke keys

To add an entry, add one new entry with a unique `key_id` and `key_value`,
build, and flash. 
Existing clients can continue using their old entry/entries while the 
new key is active. Add separate keys for staged rotation or client isolation, 
not because Meinberg and chrony require different key lists.

To rotate a entry, add the replacement entry first, deploy it, update and verify
each client, then remove the old entry in a later build.
Do not change  `key_value` under an existing Key ID during a staged rotation:
that immediately breaks clients still using the old secret.

To revoke a compromised entry, remove it, rebuild, flash, and replace 
the entry on every affected client. The removal takes effect only after the newly
built firmware is running. Never publish the entries found in the source control,
logs, packet captures, etc. (for example in support requests).

## Windows: Meinberg NTP

[Meinberg's authentication instructions](https://kb.meinbergglobal.com/kb/time_sync/ntp/configuration/ntp_authentication)
use a private key file, a `keys` directive, `trustedkey`, and a `server ... key`
association. 

The following is an example of what should be added to the `ntp.conf` file usually found in the `C:\Program Files (x86)\NTP\etc` or `C:\Program Files\NTP\etc` folder of the Windows machine(s) running Meinberg:

```text
restrict 127.0.0.1
keys "C:\Program Files (x86)\NTP\etc\ntp.keys"
trustedkey 1
server 192.168.1.24 iburst key 1
```
> Note: the `restrict 127.0.0.1` entry may already be in your ntp.conf file, if so do not duplicated it.

Use the same key ID in `ntp.keys`, `trustedkey`, and `server ... key`. For the
example above, the relevant `ntp.keys` line is:

```text
 1 SHA256 5630344F527233585A77537A4F30364D55654F62656241654A33596E3071796F
```
> With the real contents copied from line(s) below "Authorization key(s) for use with Meinberg" in the ESP32 console log.

 Copy the value after `Authorization key(s) for use with Meinberg ...` from the server's console log as
into the `ntp.keys` file. **Do not copy `key_value` directly into `ntp.keys`:
the console log entry is the client format.**

Restart the Meinberg NTP Daemon after any configuration or key-file change.

To confirm everything is working as expected, use the Windows Command Line command:

```
"C:\Program Files (x86)\NTP\bin\ntpq" -4 -c as 127.0.0.1
```
and you should see results simular to this:

<div style="margin-left: 40px">
<pre><code>
ind assid status  conf reach auth condition  last_event cnt
===========================================================
  1 36257  f61a   yes   yes   ok   sys.peer    sys_peer  1
</code></pre>
</div>

The [reference `ntpd` 4.2.8 authentication documentation](https://www.ntp.org/documentation/4.2.8-series/authentic/)
describes the matching keyed-digest construction: SHA256 over the secret
concatenated with NTP packet fields, excluding the MAC. The firmware uses the
first 20 digest bytes so its NTPv4 trailer is 24 bytes. Record the exact
Meinberg installer and `ntpd` build, capture no secrets, and verify both an
authenticated request at the server and `auth=ok` at the client before claiming
support. For *unauthenticated* time only, use the existing
[Windows setup instructions](../Setup.md#windows--meinberg-ntp-daemon-recommended).

## Linux: chrony

Chrony's [configuration manual](https://chrony-project.org/doc/latest/chrony.conf.html)
documents a `key` option for a `server` and a `keyfile` containing numbered
keys. 

Here is an example of what the `etc/chrony/chrony.conf` file should contain:

```text
keyfile /etc/chrony/chrony.keys
server 192.0.2.10 key 1 version 4 iburst
authselectmode require
```
Here too is an example of what the `etc/chrony/chrony.keys` file should contain:
```
 1 SHA256 HEX:5630344F527233585A77537A4F30364D55654F62656241654A33596E3071796F
```
> With the real contents copied from line(s) below "Authorization key(s) for use with Chrony" in the ESP32 console log.
>
Copy the value after Authorization key(s) for use with Chony ... from the server's console log into the chrony.keys file. Do not copy key_value directly into ntp.keys: the console log entry is the client format.

Restart the appropriate
`chrony`/`chronyd` service after editing the configuration
```bash
sudo systemctl restart chronyd
```

consult
`chronyc sources -v`,
`chronyc tracking`, and, if supported, `chronyc authdata` for diagnostics.

The [chrony NTP authentication code](https://raw.githubusercontent.com/mlichvar/chrony/master/ntp_auth.c)
places the Key ID before the digest while its hash implementation calculates
`SHA256(secret || packet)`, matching this firmware. Chrony truncates a NTPv4
SHA256 digest to fit the 24-byte MAC trailer. `authselectmode require` controls
source selection; it cannot repair an incorrect key, Key ID, or packet profile.
Record the exact package version and crypto backend, then verify a signed request
and reply before claiming support. For unauthenticated time, use the existing
[Linux setup instructions](../Setup.md#linux) instead.

To confirm everything is working as expected, use these two Terminal Line commands:

```bash
sudo chronyc ntpdata 192.168.1.24
```
(where you replace 192.168.1.24 with the IPv4 address of your ESP32TimeServer)

You should see an output like this:
<div style="margin-left: 40px">
<pre><code>
Remote address  : 192.168.1.24 (C0A80118)
Remote port     : 123
Local address   : 192.168.1.30 (C0A8011E)
Leap status     : Normal
Version         : 4
Mode            : Server
Stratum         : 1
Poll interval   : 4 (16 seconds)
Precision       : -13 (0.000122070 seconds)
Root delay      : 0.000000 seconds
Root dispersion : 0.001007 seconds
Reference ID    : 47505300 (GPS)
Reference time  : Fri Sep 25 12:05:32 2026
Offset          : -0.000062175 seconds
Peer delay      : 0.000191435 seconds
Peer dispersion : 0.000122104 seconds
Response time   : 0.000326989 seconds
Jitter asymmetry: +0.00
NTP tests       : 111 111 1111
Interleaved     : No
Authenticated   : Yes
TX timestamping : Kernel
RX timestamping : Kernel
Total TX        : 7
Total RX        : 7
Total valid RX  : 7
Total good RX   : 7
</code></pre>
</div>
and then
```bash
sudo chronyc authdata
```
You should see an output like this:
<div style="margin-left: 40px">
<pre><code>
Name/IP address             Mode KeyID Type KLen Last Atmp  NAK Cook CLen
=========================================================================
192.168.1.24                  SK     1    3  256    -    0    0    0    0
</code></pre>
</div>

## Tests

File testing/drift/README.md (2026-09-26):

# ESP32TimeServer Drift Test Instructions

## Setup and usage

### Install Python

**Windows:**
```bash
winget install --id Python.Python.3.14 -e
```

**Linux:**  
Look up the command for your distribution. For example:
```bash
sudo apt install python3
```

### Install Needed Libraries

Both Windows and Linux:
```bash
pip install numpy
```
```bash
pip install scipy
```

---

## Usage Notes

1. Flash two ESP32TimerServers with the release of the ESP32TimeServer software you wish to test.
   - One ESP32TimeServer (**master**) must be used to discipline the clock on the computer on which the drift test runs.
   - The second ESP32TimeServer (**reference**) is used as a reference server.

2. Edit the `drift.py` Python test script and update the values for your system and desired test scenario:
   ```python
   External_Pool_1 = "time.nrc.ca"
   External_Pool_2 = "0.ca.pool.ntp.org"
   ESP32TimerServer_master = "192.168.7.24"
   ESP32TimeServer_reference = "192.168.1.24"
   overall_report_duration_minutes = 120 
   ```

3. Stop any system-wide network time service (such as with OPNsense).

4. Ensure the computer which will be running the drift test is disciplined by the ESP32TimerServer.

5. Restart the time server service on the computer that will be running the drift test  
   *(this ensures a fresh time sync with the ESP32TimerServer_master)*.

6. Run the drift test:
   ```bash
   py drift_test.py
   ```
   - When run, it will immediately show you when the test is expected to conclude.
   - tests series will be run immediately when the script starts, and every half hour afterwards
   - As it runs, it will provide a status update of its progress
   - When complete, the script will show you that it is complete.
   - This will (re)create a file called `gathered_data.txt`.
   - When complete, the script will show you that it is complete.

7. When the drift test concludes, restart any system-wide network time service stopped in step 3 above.

8. Run the review script:
   ```bash
   py review.py
   ```
   - This will provide a review and analysis of the data found in the `gathered_data.txt` file.
   - Results will be (re)created in a file called `final_report.txt`.
   - Additionally, the script will show you those results.

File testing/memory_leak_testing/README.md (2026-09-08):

# Memory Leak Test Instructions

## Prerequisites

- Have an MQTT broker running (such as [Eclipse Mosquitto](https://mosquitto.org/))
- Have a way to connect to it to see published results 
  (such as [MQTT Explorer](https://mqtt-explorer.com/))

## Setup

1. **Set the ESP32TimeServer up to publish via MQTT**

   In the `ESP32TimeServerSettings.h` file set:

   - `MQTT_ENABLED` to `1` (Enabled)
   - `MQTT_MEMORY_REPORTING_ENABLED` to `1` (Enabled)
   - Set the values for:
     - `MQTTServerIPAddress[]`
     - `MQTTPort`
     - `MQTTUsername`
     - `MQTTPassword`
     - `MQTTBrokerRetain` to `1`
     - `MQTTReportingPeriod` to a workable time frame for examining results, 
        such as `120` (2 minutes)

1. **Build, flash and physically set up the ESP32TimeServer**

2. **View the published results with a tool such as MQTT Explorer**

   The reported values in the memory section should be expected to change over 
   the first few publications, but then generally remain constant over time. 
   Having that said, minor amounts of ebb and flow are ok, but a general
   trending decrease in any of the reported values over time is not.

## Pro tip

With Mosquitto installed ( https://mosquitto.org/ ) here's an example CLI 
command which may be used to monitor esp32TimeServer's publications and 
write (append) them to a file:

### Windows:
```bash
"c:\program files\mosquitto\mosquitto_sub" -h MQTTServerIPAddress -u MQTTUsername -P MQTTPassword -t "ESP32TimeServer/report" -k 60 >> json_records.txt
```

### Linux
```bash
mosquitto_sub -h MQTTServerIPAddress -u MQTTUsername -P MQTTPassword -t "ESP32TimeServer report" -k 60 >> json_records.txt
```
( On most Linux distributions, mosquitto_sub is installed into /usr/bin/mosquitto_sub )

### macOS
```bash
mosquitto_sub -h MQTTServerIPAddress -u MQTTUsername -P MQTTPassword -t "ESP32TimeServer/report" -k 60 >> json_records.txt
```
( If installed via Homebrew, the path is typically /usr/local/bin/mosquitto_sub 
or /opt/homebrew/bin/mosquitto_sub on Apple Silicon. You can check with:
```bash
which mosquitto_sub
```

Where MQTTServerIPAddress, MQTTUsername, and MQTTPassword are the 
values for these fields in the `ESP32TimeServerSettings.h` file.

Here too is a python script which may be used to create a comma separated 
values (.csv) file from the output of the above (for import to program 
such as Excel):

```python
#
# Copyright Rob Latour, 2026
# License: MIT
# Website: https://github.com/roblatour/ESP32TimeServer
#

import json
import csv

INPUT_FILE = "json_records.txt"
OUTPUT_FILE = "json_records.csv"

def flatten_json(obj, prefix="", out=None):
    """Recursively flattens nested JSON objects."""
    if out is None:
        out = {}

    for key, value in obj.items():
        full_key = f"{prefix}.{key}" if prefix else key

        if isinstance(value, dict):
            flatten_json(value, full_key, out)
        elif isinstance(value, list):
            # Convert lists to JSON strings
            out[full_key] = json.dumps(value)
        else:
            out[full_key] = value

    return out

rows = []

with open(INPUT_FILE, "r") as f:
    for line in f:
        line = line.strip()
        if not line:
            continue

        try:
            data = json.loads(line)
        except json.JSONDecodeError as e:
            print("Skipping invalid JSON line:", e)
            continue

        flat = flatten_json(data)
        rows.append(flat)

# Collect all possible CSV columns
all_keys = set()
for row in rows:
    all_keys.update(row.keys())
all_keys = sorted(all_keys)

# Write CSV
with open(OUTPUT_FILE, "w", newline="") as csvfile:
    writer = csv.DictWriter(csvfile, fieldnames=all_keys)
    writer.writeheader()
    writer.writerows(rows)

print("CSV written to", OUTPUT_FILE)
```

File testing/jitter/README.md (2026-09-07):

# Determining NTP Jitter on Linux, Windows, and macOS

NTP jitter is a measure of the variation in network delay and time offset between a client and its NTP server(s). Lower jitter generally indicates a more stable and accurate time source.

---

# 1. Linux

## Recommended Method: Chrony

Most modern Linux distributions use **Chrony** rather than the older `ntpd`.

### Verify Installation

```bash
chronyc tracking
```

Key metrics:

- **RMS offset**: Overall time synchronization stability.
- **Root delay**: Total network delay to the reference clock.
- **Root dispersion**: Estimated clock error.

For source-specific jitter information:

```bash
chronyc sourcestats
```

The **Std Dev** column provides the best approximation of NTP jitter for each source.

### Installation

**RHEL / Rocky / AlmaLinux**

```bash
sudo dnf install chrony
```
```bash
sudo systemctl enable --now chronyd
```

**Ubuntu / Debian**

```bash
sudo apt update
```
```bash
sudo apt install chrony
```
```bash
sudo systemctl enable --now chrony
```

More information: https://chrony-project.org/documentation.html

## Alternative Method: NTPD

```bash
ntpq -c rv
```

Look for:

```text
jitter=0.345
```

The **jitter** variable is reported directly by NTP.

---

# 2. Windows

Windows includes the **Windows Time Service (W32Time)** by default.

## Native Windows Method (W32Time)

### Check Current Status

```cmd
w32tm /query /status
```

### Estimate Jitter Using Stripchart

```cmd
w32tm /stripchart /computer:time.windows.com /samples:20 /dataonly
```

Example:

```text
10:00:01, +0.0012345s
10:00:03, +0.0013450s
10:00:05, +0.0012100s
```

Review the variation between offset measurements. Greater variation indicates higher jitter.

### Installation

No installation is required. `w32tm.exe` is included with supported Windows releases.

## Alternative Method: Meinberg NTP

Meinberg provides a Windows distribution of the reference NTP implementation, including tools such as **ntpd** and **ntpq**. The package also includes monitoring utilities for viewing NTP performance. citeturn3search26turn3search28

### Check Jitter

Open an elevated command prompt and run:

```cmd
ntpq -c rv
```

Look for a line similar to:

```text
jitter=0.182
```

This value is the NTP daemon's calculated jitter and is generally more useful than estimating jitter from stripchart output.

### View Peer Statistics

```cmd
ntpq -p
```

This displays reachability, delay, offset, and peer statistics for configured NTP servers.

### Installation

Download and install the Meinberg NTP package for Windows:

https://www.meinbergglobal.com/english/sw/ntp.htm

Installation is typically a standard Next → Next → Finish process. The installer deploys the NTP service and associated utilities. citeturn3search26

---

# 3. macOS

macOS includes the **sntp** utility by default.

## Query an NTP Server

```bash
sntp -d pool.ntp.org
```

or

```bash
sntp -d time.apple.com
```

The `-d` option displays detailed timing information, including offset measurements.

### Basic Query

```bash
sntp pool.ntp.org
```

## More Detailed Analysis with Chrony

Install Chrony:

```bash
brew install chrony
```

Then run:

```bash
chronyc sourcestats
```

Review the **Std Dev** column as the jitter indicator.

### Homebrew

If Homebrew is not installed, see:

https://brew.sh

---

# Quick Reference

| OS | Tool | Command | Jitter Indicator |
| --- | --- | --- | --- |
| Linux | Chrony | `chronyc sourcestats` | `Std Dev` |
| Linux | NTPD | `ntpq -c rv` | `jitter=` |
| Windows | W32Time | `w32tm /stripchart` | Offset variation |
| Windows | Meinberg NTP | `ntpq -c rv` | `jitter=` |
| macOS | sntp | `sntp -d server` | Offset variation |
| macOS + Chrony | `chronyc sourcestats` | `Std Dev` |

**Best Practice:** Collect at least 50–100 samples over several minutes and use the standard deviation of the measured offsets as the jitter value. This provides a more representative measurement than a single snapshot.

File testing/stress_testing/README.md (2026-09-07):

## Stress Testing ESP32TimeServer

Please see this open source program (for Windows) for stress testing ESP32TimeServer:

[Time Server Stress Test](https://github.com/roblatour/TimeServerStressTest)

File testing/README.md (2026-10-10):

# Ways to test an NTP Time Server

## Functional testing

### Internal functional health checks

ESP32TimeServer has a built in self health check logic which is disabled by default.  Enabling it allows the program to basically run tests on itself at startup - for example it will send itself an NTP request, receive and process it as it would any other external request, once done it will verify ther  results - including metrics accumulated for MQTT reporting.  In all there are 37 such tests.  

To enable a self health check set `STARTUP_HEALTH_TEST_ENABLED` to `1` near the top
of the `main.cpp` file. Once done, at startup the program will run its health tests and report the results in the console log.

This feature is disable by default as it is primary purpose is to help ensure, pre-release, code changes development do not introduce  unexpect regression issues.  Also it adds time to startup time delaying the point at which the server can come online (be open for business).

Of note: results may be misleading depending setup. For example, health checks may 'Pass' all
IPv4 tests yet 'Fail' all IPv6 tests, not because of a problem with the program but because
the network it is running on doesn't support IPv6.

### External functional testing

[ESP32TimeServerTester](https://github.com/roblatour/ESP32TimeServerTester) is an independent functional NTP server testing tool.  It tests much of the same functionality as the Health check tests do, but from an external standpoint.

### RFC 9769 compliance testing
RFC 9769 compliance testing ensures network time synchronization implements the RFC 9769 NTP interleaved modes specification for NTPv4 replies. While this testing is covered off by two testing methods above, a python testing tool is also available to specifically test RFC 9769 compliance, for more information please see: [/testing/RFC_9769_compliance/README.md](/testing/RFC_9769_compliance/README.md)

## Memory Leak Testing
A memory leak occurs when a program allocates memory but fails to release it when no longer needed. Over time, leaked memory can degrade performance and potentially cause application failures.  For more information please see: [/testing/memory_leak_testing/README.md](/testing/memory_leak_testing/README.md)

## Stress Testing
Stress testing evaluates how a program performs under extreme workloads or resource constraints beyond normal operating conditions. It helps identify stability issues, bottlenecks, and failure points. For more information please see this open source stress testing tool: [Time Server Stress Test](https://github.com/roblatour/TimeServerStressTest)

## Quality of Service

### Jitter
Jitter is the variation in network delay between NTP messages exchanged with a time server. High jitter can reduce the accuracy and stability of time synchronization. For more information please see: [/testing/jitter/README.md](/testing/jitter/README.md)

### Drift
Drift is the gradual deviation of a computer's clock from the correct reference time due to hardware clock inaccuracies. NTP compensates for drift by regularly synchronizing the system clock with a time source. For more information and a python based drift testing tool please see: [/testing/drift/README.md](/testing/drift/README.md)

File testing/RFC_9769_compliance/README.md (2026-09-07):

# Setup and usage fo the rfc976_test.py script:

## Install Python: (if not already installed)

  Windows:
  ```cmd
     winget install --id Python.Python.3.14 -e
   ```

  Linux:
     look up the command for your distribution, but for example:

   ```bash
     sudo apt install python3
   ```

## Run the python script from the command line:

```cmd
py rfc9769_test.py --target x.x.x.x
```
( where x.x.x.x is the IP address for your esp32TimeServer, for example 192.168.1.24 )

Additional CLI options include: --timeout, --retries, --verbose

Here is a sample report run with `py rfc9769_test.py --target 192.168.1.24 --verbose`

```
==============================================================================

                     NTP RFC 9769 Protocol Validation Test

                           Testing IP: 192.168.1.24
                      Local Time: 2026-09-07 08:26:29 AM

------------------------------------------------------------------------------

[+] Running Standard NTPv3 Validation Test...
 |-- Sending Standard Request packet...
 |-- Attempt 1/3: sending packet to ('192.168.1.24', 123)
 |-- Received Payload metadata: NTPv3, Mode=4, Stratum=1, LI=0
 |-- Server Reference TS: 3997772789.000037
 |-- [PASS] Standard loopback handshake validation verified (raw bytes match).

[+] Running Interleaved NTPv3 Validation Test...
 |-- Sending Interleaved Handshake Request packet...
 |-- Attempt 1/3: sending packet to ('192.168.1.24', 123)
 |-- Server Echoed Origin TS:   3997772789.5198298 (expected prior client T4)
 |-- Server Receive TS (T2):     3997772790.5283313
 |-- Server Transmit TS (T3):    3997772789.5181813 (expected prior server T3)
 |-- [PASS] RFC 9769 interleaved timestamp validation verified.

[+] Running Standard NTPv4 Validation Test...
 |-- Sending Standard Request packet...
 |-- Attempt 1/3: sending packet to ('192.168.1.24', 123)
 |-- Received Payload metadata: NTPv4, Mode=4, Stratum=1, LI=0
 |-- Server Reference TS: 3997772791.000033
 |-- [PASS] Standard loopback handshake validation verified (raw bytes match).

[+] Running Interleaved NTPv4 Validation Test...
 |-- Sending Interleaved Handshake Request packet...
 |-- Attempt 1/3: sending packet to ('192.168.1.24', 123)
 |-- Server Echoed Origin TS:   3997772791.531306 (expected prior client T4)
 |-- Server Receive TS (T2):     3997772792.5343633
 |-- Server Transmit TS (T3):    3997772791.5296874 (expected prior server T3)
 |-- [PASS] RFC 9769 interleaved timestamp validation verified.

------------------------------------------------------------------------------

                NTP RFC 9769 Protocol Validation Test Complete

                          Copyright Rob Latour, 2026
                                License: MIT
              Website: https://github.com/roblatour/ESP32TimeServer

==============================================================================
```

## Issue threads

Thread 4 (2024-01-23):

Compile Errors

ianburton20, 2024-01-23:
Rob - thanks for this project. I get a couple of compile errors - any suggestions where I'm going wrong? Thanks

ESP32TimeServer_Test1.ino: In function 'void setDateAndTimeFromGPS(void*)':
ESP32TimeServer_Test1:355:19: error: aggregate 'tm wt' has incomplete type and cannot be defined
         struct tm wt;
                        ^~  (up arrow points to wt)
ESP32TimeServer_Test1:369:34: error: 'mktime' was not declared in this scope
           candidateDateAndTime = mktime(&wt) + 1; // not sure why the + 1 but it is
                                                     ^~~~~ (up arrow points to mktime)

roblatour, 2024-01-23:
Hmmm, I just compiled it myself and it works fine.

Did you copy the code exactly?

If yes, I'm guessing your issue is associated with a time library someplace on your system.

I did a quick google and found a variety of people having the same problem with other projects.  Here are two examples:
https://community.platformio.org/t/issue-with-struct-tm/19017/4
https://community.platformio.org/t/aggregate-tm-timeinfo-has-incomplete-type-and-cannot-be-defined/13715

Also, it if helps, the ESPTime.h library I am using is this one:
https://github.com/fbiego/ESP32Time
Originally, when I compiled my code I was using version 2.0.0 and it compiled fine.  Following your post I upgraded it to version 2.0.4 (the current version) and it also compiled fine.   Are you perhaps using an older library?

ianburton20, 2024-01-23:
Rob – Thanks. You have given me something definite to follow up. I’ll let you know how I get on. Thanks again – Ian

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

ianburton20, 2024-01-24:
Rob

I’m OK with ESP32Time.h – using v2.0.4

But – I’m back into…

void setDateAndTimeFromGPS(void *parameter)

and that structure

struct tm wt;

error: aggregate 'tm wt' has incomplete type and cannot be defined

also….

I can’t find where mktime is declared in….

candidateDateAndTime = mktime(&wt) + 1; // not sure why the + 1 but it is

What version of  https://github.com/khoih-prog/Timezone_Generic

Are you using?

You #include <Timezone.h> but the library needs you to #include <Timezone_Generic.h>   - so I can’t fathom the version.

Thanks again.

Ian

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

roblatour, 2024-01-24:
I just checked my libraries, it looks as if I'm now using
https://github.com/JChristensen/Timezone  (version 1.24)
for Timezone.h

Not sure when I switched to it, or why, but it seems to work with this project too.

roblatour, 2024-08-10:
closed due to lack of feedback

roblatour, 2024-08-10:
closed due to lack of feedback (no activity in over six months)

Closed 2024-08-10.

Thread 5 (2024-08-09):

TimeZone_Generic fails to install

Braehead, 2024-08-09:
I'm new to you ESP32TimerServer project and trying to get all the libraries loaded.  Only Issue I have is with TimeZone_Generic.  The library install fails over the wire library not available as a dependency (core of ESP32 and present on my system).  The TZ_G library is now Archived in GH and so issues can't be raised.  Wire is really now known as TwoWire (on most Arduino based boards) and this maybe where the issue lays.  I'm using Arduino 2.3.2 and ESP32 3.0.3.

Any suggestions of how to move forward?

roblatour, 2024-08-09:
The program is a year and a half old and it looks like it has run into a breaking change in the Arduino environment since then.

I ran some tests and changing the version of the esp32 board manager to 2.0.13 corrects the problem.

This is done in Arduino in the menu bar as follows:
Tools - Board: (whatever) - Boards Manager ...  - search for "esp32" (without the quotes) - esp32 by Espressif Systems - select 2.0.13 from the dropdown box - Update

when done exit and restart the Arduino program.

Please let me know if this fixes it for you, and if so I will update the comments in the program to mention this.

Braehead, 2024-08-10:
First thank you for coming back promptly.  Very much appreciated.  Sorry for the delay, I wanted to try some additional systems before detailing further findings.  And I know the issues of platform upgrades, sadly.

On the original machine.  Installing the Arduino ESP32 support (2.0.13) did not help.  Nor did this help on another system.  And I upgraded the Espressif platforms from 3.0.3 to 3.0.4.  Both the Arduino ESP32 and Espressif ESP32 systems have the Wire library as part of the core installs.  And I can include them into projects.  But trying to install the TZ_G library fails - "Failed to install. No valid dependencies solution found: dependency 'Wire' is not available.  I down graded my Espressif library to 2.0.13 as you suggested.  Restarted the IDE and still fails to install.  Versions verified.  Went back to 2.0.10 of Espressif ESP32 - still the same.  The error is immediate.  I have gone back to 3.0.4 as I have code to compile.  It's not the Arduino ESP32, as the first system does not have those boards loaded.

roblatour, 2024-08-10:
What a mess.

However, I am using the Arduino IDE version 2.3.2 and as mentioned earlier the esp32 board manager to 2.0.13.

Maybe the version of the IDE is the difference?

Braehead, 2024-08-10:
OK.  Lets just get the versions and settings correct:

Arduino IDE 2.3.2 - check.

ESP32 Board library.  There are TWO ESP32 libraries that could be version 2.0.13.  The 'esp32' by Espressif and 'Arduino ESP32 Boards' by Arduino.  I presume we are talking about the Espressif boards definitions because that contains the 'Olimex ESP32 POE ISO'.  And the Arduino version does not.  I have both loaded due to also using Arduino based ESP projects.

I also presume the basic simple Olimex board as the compilation target?  As some have PSRAM and other specification variants.  Did some compile tests (without the TZ-G library available), and getting lots of unexpected errors.  I can't believe this much has changed since your original authorship took place.  So this has thrown further confusion into the mix.  But I'm ignoring these issues at the moment.  And focusing on why this TZ_G library refuses to install.  Wire is available in pretty much all MCU core board installs.  So why does it give an error.  I use I2C all over the place, and on various MCUs.  So it it present compiles and executes.

I think the author of TZ_G has archived all his GH publications because it blocks anyone raising an issue or discussing.  But it renders the project as 'dead', but downloadable.

I have a fairly vanilla Arduino IDE install on a Linux box which I will test in the morning.  And I will also look at VSStudio and PlatformIO too.

roblatour, 2024-08-10:
Yes, I am using the ESP32 by Espressif Systems board library.

Also, under the Arduino menu - File - Preferences - Additional Board Managers URLs I have the following links:
https://dl.espressif.com/dl/package_esp32_index.json
https://raw.githubusercontent.com/espressif/arduino-esp32/gh-pages/package_esp32_index.json

Here are the relevant settings under the Arduino menu - Tools:

Board: "OLIMEX ESP32-PoE-ISO"

Core Debug Level: "None"
Erase All Flash Before Sketch Upload: "Disabled"
Flash Frequency: 80MHz"
Partition Scheme: "Default"
Upload Speed: "115200"

Here is a screen shot of all the installed libraries that appear in Library manager (most have nothing to do with this project, but included here as it may be helpful)

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

Braehead, 2024-08-12:
OK, thanks for all this info, very much appreciated.  I have a clean install of the Ardunio IDE on a clean system.  So I'm building up and knocking down to get further along.  Clearly works for you, but not me.  Give me a few days to pin this down (or close to) and hopefully I'll get back to you with notes or whatever.

It is probably changes between IDE 1 & 2.  IDE 1 is looking OK with some avoidances, but IDE 2 keeps rejecting unless you came from IDE 1 with the library already installed.

roblatour, 2024-08-12:
Ok - please let me know if you would like me to send you / post the used libraries as listed here:
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

roblatour, 2024-08-13:
Glad to hear it.

I've found the Arduino platform increasingly frustrating over the years, for reasons such as this one.

Hope the program will be of good use to you.

Cheers!

Braehead, 2024-08-15:
OK.  Progress to some degree.

The issue is to do with the cited Timezone library: DO NOT USE the linked version Timezone_Generic by khoih-prog.  AKA Khoih Hoang.  Several issues:
- Khoih archives his publications to prevent issues being raised = No support
- This version of the library appears to be a rip-off of the original by  Jack Christensen.  Use Jack's version.
- The author cross referencies many other libraries that are published by himself or may have his input.  This results in any library from this author loading all the other libraries connected with Khoih.  For Timezone_Generic, this is an extra 20+ libraries that are not required.
- It is this huge dependancy list that screws up Adruino IDE1.x and 2.x.  Causing all kinds of errors when the dependency list is processed.

I have the ESP32Time server source compiling and linking under IDE 1.x.  IDE 2.x is giving me issues still.  However, I do not beleive the new issues are to do with Timezone, now I have ignored the  Khoih version and correctly using the  Jack Christensen version.

Many thanks @BigThunderSR for listing the file from PlatformIO that lists a far simpler dependency list that works on a vanilla Arduino install.  The IDE 1.x libraries work every time after a wipe down install of the IDE.  But as yet I have failed to clean install IDE 2.x or upgrade from 1.x to 2.x and it compile without an error.  I'm working on this as the next phase.  Now the Timezone library issue is resolved.

So not an Arduino issue.  Can anyone else do some tests?  IDE 1.x now gives me a WiFi UDP not defined issue and IDE 2.x give a Timezone function issue that I have not looked into at all at the point).  These faults are probably nothing to do with the Timezone library change over.  So remove all reference to Khoih libraries please.  But hold back on any documentation issues until I can clear errors with both IDEs please.

roblatour, 2024-09-06:
As this hasn't been updated in a while, what I've done is updated the code in the Arduino library to specify various Arduino Settings / Libraries to use.  I still haven't had any issues building myself, but hopefully this will help others.  As needed this issue can be reopened.

Closed 2024-09-06.

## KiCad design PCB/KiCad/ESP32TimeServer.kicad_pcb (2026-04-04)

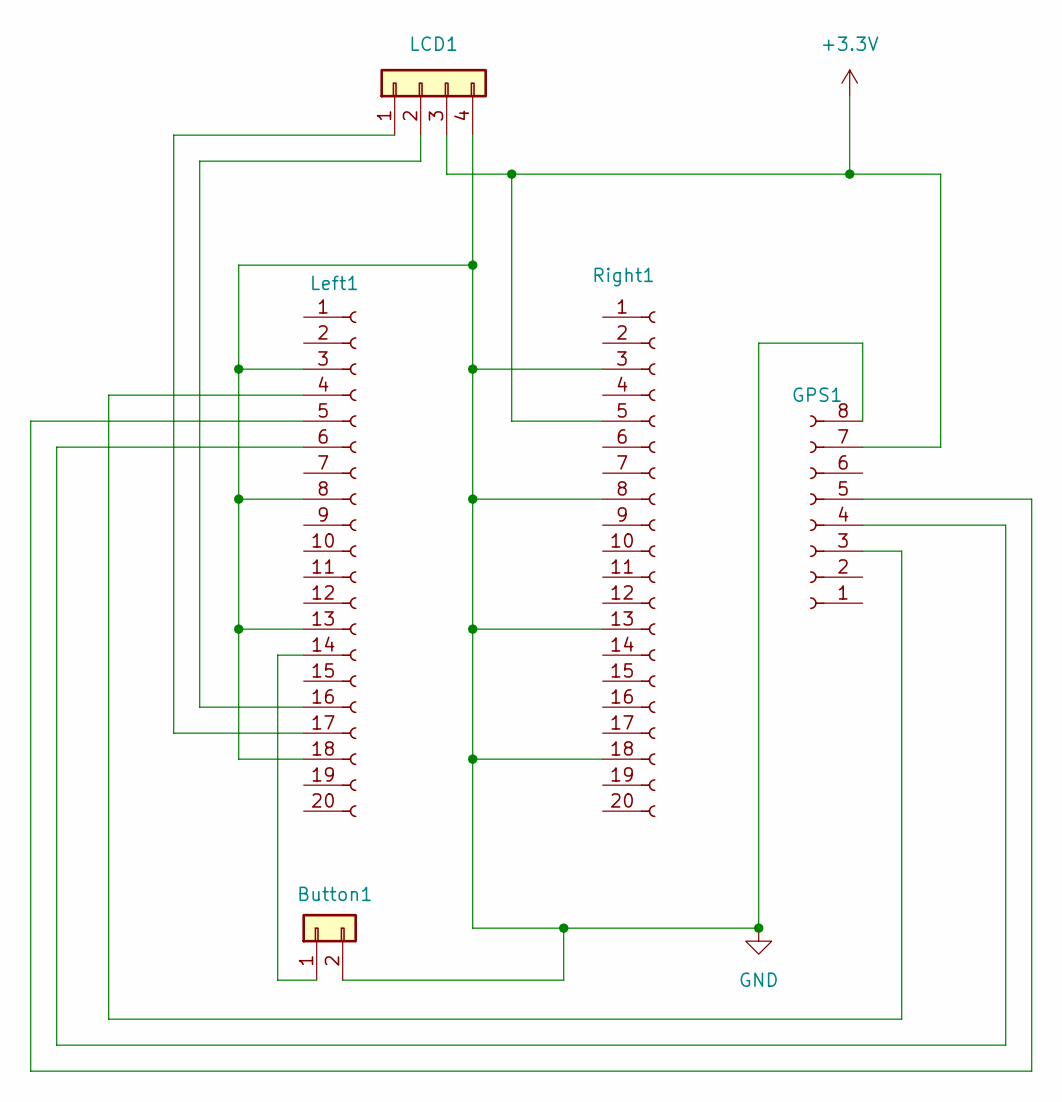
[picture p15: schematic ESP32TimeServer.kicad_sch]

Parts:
Button1: Conn_01x02; JST_PH_B2B-PH-K_1x02_P2.00mm_Vertical
GPS1: Conn_01x08_Socket; PinSocket_1x08_P2.54mm_Vertical
LCD1: Conn_01x04; JST_PH_B4B-PH-K_1x04_P2.00mm_Vertical
Left1: Conn_01x20_Socket; PinSocket_1x20_P2.54mm_Vertical
Right1: Conn_01x20_Socket; PinSocket_1x20_P2.54mm_Vertical

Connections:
+3.3V: GPS1.7, LCD1.3, Right1.5
GND: Button1.2, GPS1.8, LCD1.4, Left1.3, Left1.8, Left1.13, Left1.18, Right1.3, Right1.8, Right1.13, Right1.18
unnamed: Button1.1, Left1.14
unnamed: GPS1.3, Left1.4
unnamed: GPS1.4, Left1.6
unnamed: GPS1.5, Left1.5
unnamed: LCD1.1, Left1.17
unnamed: LCD1.2, Left1.16

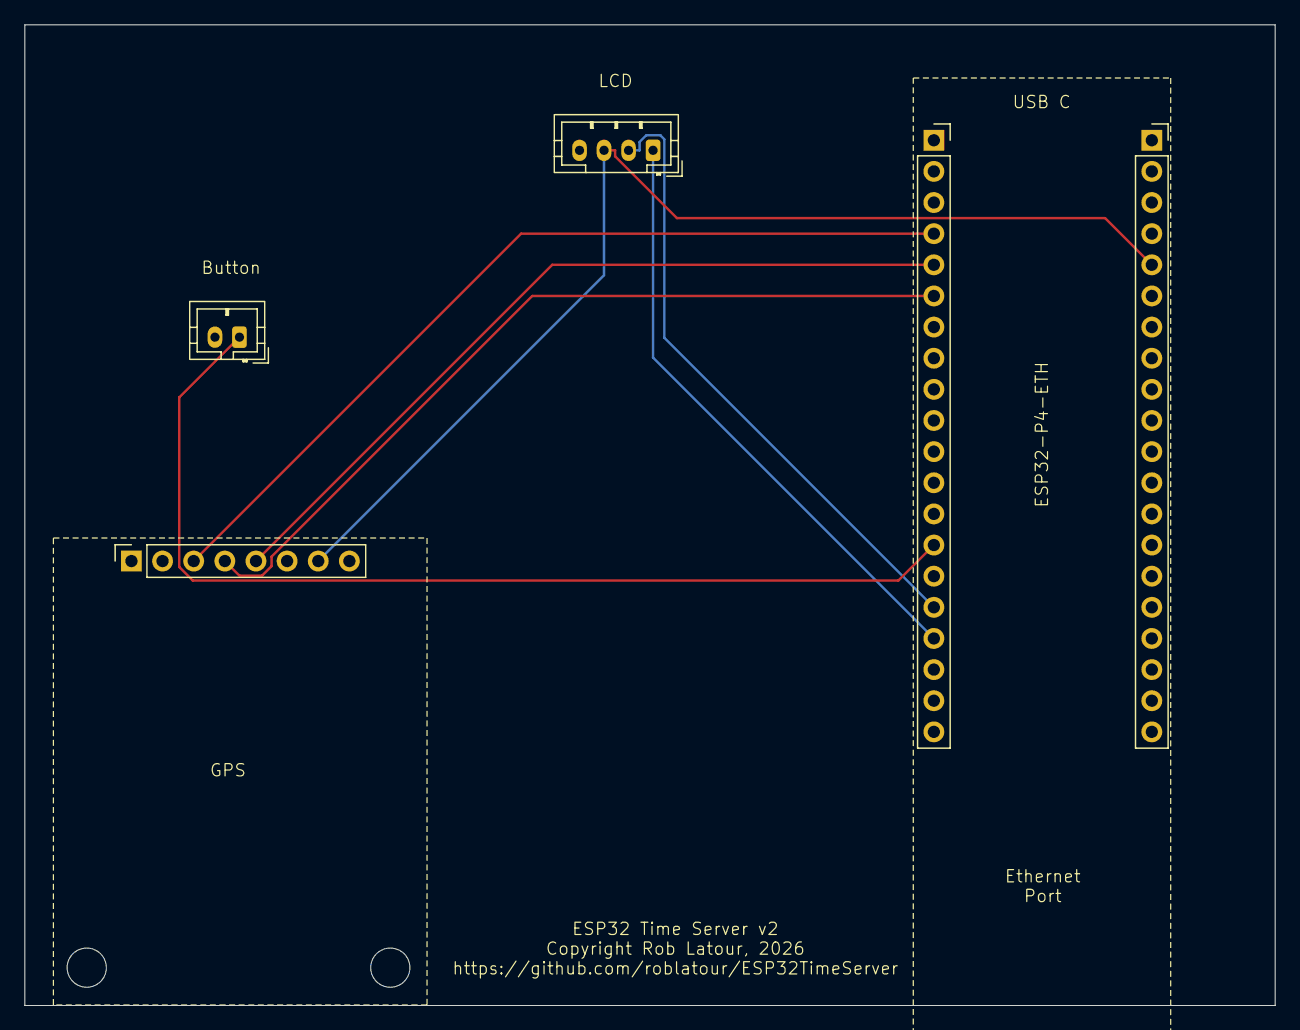
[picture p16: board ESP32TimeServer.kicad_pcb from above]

Board: 2 copper layers, 102.0 x 80.0 mm, 7 parts (0 on the bottom side), 8 nets.

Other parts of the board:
REF1, REF2: MountingHole_3.2mm_M3

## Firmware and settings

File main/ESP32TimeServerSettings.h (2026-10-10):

// ESP32 Time Server v3.0.4
// Copyright Rob Latour, 2026
// License: MIT
// Website: https://github.com/roblatour/ESP32TimeServer
//
// Note: some additional settings are defined in the ESP32TimeServerSettingsSecrets.h file
//

#pragma once
#include <cstddef>
#include <cstdint>
#include <ctime>
#include "custom/setting_types.c"
#include "ESP32TimeServerSettingsSecrets.h"

// (optional) debug support
// NOTE: setting DEBUG_ENABLED to 1 (Enabled) will degrade accuracy and performance during periods of high volume ntp requests
#define DEBUG_ENABLED 0 // 0 = Disabled; 1 = Enabled
static constexpr int serialMonitorSpeed = 115200;

// (optional) RGB LED module support; enable support for one module type below at most
#define RBG_LED_KY_016_MODULE_ENABLED 0 // 0 = Disabled; 1 = Enabled
#define RBG_LED_WS2812_MODULE_ENABLED 0 // 0 = Disabled; 1 = Enabled

static constexpr int RGB_LED_Brightness_Percent = 70;

// The LED colours below may be changed to suit your preferences, but the descriptors should remain unchanged
// For example: you can change LED_normal to blue but leave the descriptor 'LED_normal' unchanged
static constexpr RGB_LED_Colour LED_startup = RGB_LED_Colour::blue;
static constexpr RGB_LED_Colour LED_normal = RGB_LED_Colour::green;
static constexpr RGB_LED_Colour LED_sync = RGB_LED_Colour::white;
static constexpr RGB_LED_Colour LED_warning = RGB_LED_Colour::yellow;
static constexpr RGB_LED_Colour LED_alert = RGB_LED_Colour::orange;
static constexpr RGB_LED_Colour LED_critical = RGB_LED_Colour::red;
static constexpr RGB_LED_Colour LED_button_push = RGB_LED_Colour::pink;

// GPIO pin definitions for use with a KY-016 RGB LED module
static constexpr int LEDBluePin = 4;
static constexpr int LEDGreenPin = 5;
static constexpr int LEDRedPin = 6;

// GPIO pin definitions for a WS2812 RGB LED module
static constexpr int WS2812DataPin = 4;

// (optional) attached LCD support
#define LIQUID_CRYSTAL_DISPLAY_ENABLED 1 // 0 = Disabled; 1 = Enabled
static constexpr int lcdColumns = 20;
static constexpr int lcdRows = 4;
static constexpr char lcdTopLineTitle[] = "ESP32 Time Server"; // text on the LCD's top line (max 17 characters; the last 3 columns are reserved for status indicators)
static constexpr bool display24HourFormat = false;             // set to true for 24-hour format, false for 12-hour format
static constexpr bool displayHoursWithPaddedZero = false;      // set to true to pad the hour with a leading zero when less than 10, false not to pad
static constexpr bool displayTimeZone = false;
static constexpr int lcdI2CAddressPrimary = 0x27;
static constexpr int lcdI2CAddressSecondary = 0x3F;

// (optional) uptime / reset momentary button support
#define UPTIME_RESTART_BUTTON_ENABLED 1 // 0 = Disabled; 1 = Enabled
static constexpr unsigned long holdUpTimeRestartButtonForThisManySecondsToTriggerAReset = 10UL;
static constexpr int upTimeDisplayWillStayActiveForThisManySeconds = 10;
// GPIO pin definitions for the uptime / reset momentary button
static constexpr int upTimeRestartPin = 3;

// (optional) Over The Ethernet updates support
// Please also see ESP32TimeServerSettingsSecretes.h for the configuration of the OTE password.
#define OTE_UPDATES_ENABLED 1 // 0 = Disabled; 1 = Enabled
static constexpr char DeviceName[] = "ESP32TimeServer";
static constexpr uint16_t OTEPort = 3232;

// (optional) NTPv4 symmetric-key packet authentication.
// When enabled, only authenticated NTPv4 requests with a valid configured key receive signed replies.
// However, non-authenticated NTPv4 requests are still processed as normal requests without authentication.
// Please also see ESP32TimeServerSettingsSecretes.h for the configuration of symmetric keys.
#define SYMMETRIC_KEY_AUTHENTICATION_ENABLED 0 // 0 = Disabled; 1 = Enabled

// (optional) MQTT reporting support
// MQTT_ENABLED provides for current system status and activity reporting on information such as:
// uptime, number of active satellites, ntp request counts, etc.
// Additional detailed related to client activity, memory usage, and historical information can be optionally included
// When symmetric-key authentication is enabled, MQTT reporting can distinguish between authenticated and unauthenticated requests as well
// Please also see ESP32TimeServerSettingsSecretes.h for the configuration of the MQTT credentials.
#define MQTT_ENABLED 1                                     // 0 = Disabled; 1 = Enabled
#define MQTT_CLIENT_REPORTING_ENABLED 1                    // 0 = Disabled; 1 = Enabled
#define MQTT_MEMORY_REPORTING_ENABLED 1                    // 0 = Disabled; 1 = Enabled
#define MQTT_HISTORICAL_REPORTING_ENABLED 1                // 0 = Disabled; 1 = Enabled
#define MQTT_DISTINGUISH_AUTHENTICATED_REPORTING_ENABLED 0 // 0 = Disabled; 1 = Enabled
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

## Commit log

2023-01-24 initial release
    ESP32 NTP Stratum 1 Time Server
    [Time server case v37.f3d, Time server case v37.stl]
2023-07-06 minor update
    display UP Time for 10 seconds when button is pressed
2023-08-29 Time Zone setting change now only needed in ESP32TimeServerKeySettings.h file
2023-09-23 Add the current timezone to the clock display
2024-09-06 Update ESP32TimeServer.ino
    updated with comments to clarify various Arduino settings / libraries used
2025-09-02 updates to react to changes in arduino environment
2026-02-06 2026 February 6th update
    - changes for greater long term stability
    - added feature, hold down button for 10 seconds to reboot device
    [u-blox_config_keys_sorted.txt]
2026-03-24 Revise version 2 features in README.md
    Updated version 2 features for ESP32 NTP Stratum 1 Time Server in README.
2026-04-04 Version 2 release
    [Back ESP32-P4-ETH PCB.3mf, Back ESP32-P4-ETH PCB.stl, Back ESP32-P4-ETH-NoUSB.3mf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]
2026-04-05 Clarify microcontroller board description in README
    Updated the description of the new microcontroller board for clarity.
2026-04-05 Clarify new microcontroller board details in README
    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
2026-04-05 Fix grammar in Version 2 description
    Corrected grammatical error in the description of the new microcontroller board.
2026-08-06 Fix typo in ESP32-P4 module revision description
2026-08-06 early PPS Pin init
2026-08-06 Disable pull-down resistor for GPIO configuration
2026-08-06 updates for v2.4
    rx, tx, pps pin changes
    increased memory allocations for running gps_time_sync
    minor update on display; now showing x of 4 when waiting for satellite fixes
    [ESP32TimeServerSettings.h]
2026-08-10 Revise network connection instructions for ESP32 Time Server
    Updated instructions for connecting the ESP32 Time Server to the network and emphasized the importance of a static IP address.
2026-08-10 Fix typo in Setup.md regarding switches
2026-08-22 Version 2.5
    - IPv6 support has been added.
    - Optional MQTT publishing of time server stats is now available.
    For more information see: misc/esp32timeserver_json_doc.md
    - Improved GNSS Satellite lock and PPS discipline tracking and recovery.
    - When optional features are disabled in the settings their associated code will now be excluded from the executable.
2026-08-24 v2.5.2
    - Upgraded NTP response from NTPv3 to NTPv4
    - Improved the server’s IPv6 support by better handling link local requests
    - Update to the EnclosureReadme file to include a link to additional 3D models shared by a Duglum
    - Update to the 'usefull powershell commands' file
2026-08-28 version 2.6
    - Added a feature to queue MQTT publications, as needed, to a TF card; limited queuing to RAM is still available when there is no TF card
    - Faster startups when server had a satellite connection at least once before
    - GNSS Fix and PPS discipline startup requirements are now more stringent and in most cases will no longer require auto restarts on cold connections
    - Updates, displayed on the LCD, are more descriptive of the startup progress
    - Added option to request MQTT retain the most current message
    - Published MQTT client activity is now sorted by IP address
    - Added Ethernet connection check
    - Updated LCD top line warning display indicators:
    Standard 1st line display v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
    [ESP32TimeServerSettings.h]
2026-08-29 Clarify notes in README about enclosure files and ESP32-P4
    Updated notes regarding the 3D printable enclosure files and clarified compatibility for older ESP32-P4 modules.
2026-09-01 v2.7.1
    - The server now uses ESP32 Motor Control Pulse Width Modulation (MCPWM) with the 80 MHz capture timer to capture positive PPS edges from the PPSPin. This now provides 12.5 ns resolution as opposed t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
    - Added Github automated build for ESP-ID v6.1 (the lower end build checks for v5.5.5 and v6.0.2 remain)
2026-09-02 v2.7.4
    - corrections to improve drift
    - keep alive time changed from 60 seconds to 30 seconds
    [ESP32TimeServerSettings.h]
2026-09-07 v2.8
    - Support for RFC 9769-compatible interleaved responses - including hardware level time stamping. This drastically reduces jitter (the variation in successive clock offset measurements) between a client and server using RFC 9769-compliant NTP requests.
    - Server maximum throughput has been significantly increased, maxing out at just over 10K requests/second in stress testing
    - Added instructions, tools, and links for determining / testing: jitter, drift, RFC 9769 compliance, memory, and server performance under stress.
    - NOTE: Starting with this release esp32TimeServer must be built using ESP-IDF v6.1 (or greater) ( https://github.com/espressif/esp-idf/releases/tag/v6.1 )
2026-09-14 Update RFC 9769 support description in README
    Clarified support for RFC 9769 on IPv4 NTP requests, emphasizing hardware level time stamping and reduced jitter.
2026-09-16 Refactor GPS module wiring instructions in README
    Updated section headers and added hints for GPS module wiring.
2026-09-16 v2.9
    - Added hardware timestamping on NTPv3 and NTPv4 for IPv6 requests
    - Experimental support added for non-compliant U-Block GNSS receivers
    - Added optional startup health check
    - Increased throughput and stability for high volume requests per second
    - various changes to reduce RAM requirements
    - (for developers) improve the method identifying needed xTaskCreatePinnedToCore memory adjustments following code changes
    - Support for receivers without a PPS Pin has been dropped in this release - related code will be removed in a future release
    [json_message_calculator.xlsx]
2026-09-16 Fix GPS/GNSS antenna description in README.md
2026-09-17 Enhance GNSS power supply stability advice
    Updated hint section to emphasize the use of a capacitor for GNSS power supply stability.
2026-09-21 v2.9.1
    - Added support for a (KY-016) status LED.
    - External NTP requests will now be ignored until the 'Open for business' console message is displayed.
    - Improve startup times for U-Blox compliant receivers, especially on cold boots.
    - TF card setup will only happen when MQTT is enabled and QOS > 0.
    - In the PPS Qualification period the LCD now shows how many seconds remain in the dwell period once 10 of 10 PPS Edges have been detected.
    Note: PPS qualification requires 10 good edges with no bad ones after the 10th all over a 15 second time frame.
    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
2026-09-21 Add optional reset button pin information for ESP32-P4-ETH
2026-09-23 v2.9.2
    - Corrected a problem with reporting of controlled restart messages when MQTT_QOS = 0
    - Added MQTT messages for all control restart behaviours
    for more information please see: https://github.com/roblatour/ESP32TimeServer/blob/main/misc/esp32timeserver_json_doc.md
    - Now writing MQTT payload messages to the console log so the output appears in the standard console log colouring
    [ESP32TimeServerSettings.h]
2026-09-26 v3
    - NTPv4 Symmetric-key authentication support added for Windows clients using Meinberg and Linux clients using chrony.
    For more information, please see misc/symmetric_key_authentication_setup.md
    - Normal loss of an Ethernet connection no longer causes a controlled reboot, loss of Ethernet connection due to the
    server being overwhelmed by too many requests will still cause a controlled reboot (by design).
    - Improvements to the drift_test python script (make best use of allotted testing period, provide status updates as tests progress)
    [ESP32TimeServerSettings.h]
2026-09-27 Fix typos and improve clarity in Linux setup instructions
    Corrected minor typos and formatting issues in the Linux setup instructions for ESP32 Time Server. Ensured consistency in command syntax and clarified group membership check.
2026-09-28 Update RGB LED GND connection details in README
    Clarify GND connection for RGB LED and suggest resistor use.
2026-09-28 Fix typos in resistor notes in README
    Corrected typographical errors in the README regarding resistor notes.
2026-09-30 v3.0.1
    - added load shedding:
    Previously:
    1, in normal load situations, all incoming NTP requests receive a reply
    2. in heavy load situations, near the server's ability to handle all incoming requests, the program would reply to as many requests as it could beyond which some requests would not receive a reply
    3. in very heavy load situations, marginally above the server's ability to handle all incoming requests, some requests would not receive a reply but if the program became overwhelmed it would perform a controlled reboot
    4. in extreme load situations, many or most requests would not receive a reply and the program would stall after which time no requests would receive a reply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
    [ESP32TimeServerSettings.h]
2026-10-01 v3.0.2
    - Added support for a WS2812 RGB LED module, with continued support for a KY-016 RGB LED module.
    With this change neither or either a KY-016 or WS2812 module may be used (but not both at the same time).
    The WS2812 module provides better mixed colours and requires only one GPIO pin vs the three needed for the KY-016.
    - Brightness is now controlled in the ESP32TimeServer.h settings file for the KY-16 (new with this release) and the WS2812.
    See the main page for wiring instructions for the WS2812 and KY-016.
    - Corrected time with padded zero for hours option
    [ESP32TimeServerSettings.h]
2026-10-05 Fix README formatting for WS2182 support
    Fixed formatting issue with WS2182 RGB LED support bullet point.
2026-10-06 v3.0.3
    - Added an option to change the LCD's top line message
    - corrected LCD time display
    - updated MQTT buffer sizes + supporting spreadsheet
    - added some code to throw errors at build time on bad settings (more will likely be added in future releases)
    [json_message_calculator.xlsx]
2026-10-10 v3.0.4
    - added new options values for displaying addresses on the LCD - including rotating IPv4/IPv6 addressees, and showing
    either a status line or entirely blank line for privacy reasons
    - provide for, in some cases, faster startup with Ethernet and GNSS receiver setups now happening in parallel
    - ensure the highest scope IPv6 addresses are assigned when available
    - some additional information displayed in console prior to the Open for business message
    - updates to https://github.com/roblatour/ESP32TimeServer/tree/main/testing/README.md
    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
2026-10-12 Fix warning about powering ESP32-P4 boards
    Corrected wording for clarity regarding power supply warnings.
2026-10-12 Correct warning about power supply usage
    Fix typo in warning about powering ESP32-P4-ETH.
2026-10-21 v3.0.5
    - corrected interleaved requests when the client's source port didn't match the destination NTP_PORT
    - Ublox compliant GNSS receivers set to Stationary GNSS mode at startup for improved timing accuracy
    - added python testing to verify server alignment
    (for more information please see: https://github.com/roblatour/ESP32TimeServer/blob/main/testing/server_alignment/README.md )
    - updated to use Espressif's Ethernet and OTE update (TCP 3232) processes in place of the Arduino Ethernet and OTE update (UDP 3232) processes
    (for more information please see: https://github.com/roblatour/ESP32TimeServer/blob/main/misc/UsefullPowerShellCommands.md )
    - improved accuracy with ESP32-P4 chips rel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
2026-10-26 Modified PCB Layout
    Amended PCB to work with new pin assignments, added labels to the LCD connector.
2026-11-06 Revise GPIO pin information and clean up README
    Updated GPIO pin references in the README and removed outdated notes about the LCD connector.
2026-11-07 v4
    major release - now supporting the ESP32-S31 and PTP - see release notes
2026-11-07 Fix typo in README for ESP32TimeServer
2026-11-07 Fix ESP32-S31 Function CoreBoard reference
    Updated references to ESP32-S31 Function CoreBoard-1 in the README.
2026-11-08 Update GPS/GNSS module and antenna recommendations
    Corrected spelling and added affiliate links for GPS/GNSS module and antenna.
2026-11-08 Update links and optional components in README
    Updated links for ESP32-S31 Function CoreBoard-1 and GPS/GNSS antenna. Adjusted optional components links for better accuracy.
2026-11-12 Enhance README with new case designs for ESP32 boards
    Updated user build section with new case designs for ESP32-S1 and ESP32-P4 boards.
2026-11-12 3D Print model for the ESP32-S31 Functional Coreboard 1
